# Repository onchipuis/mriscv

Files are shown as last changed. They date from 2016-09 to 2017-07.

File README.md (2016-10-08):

# mriscv

Building a pure RV32I Toolchain
-------------------------------

The default settings in the [riscv-tools](https://github.com/riscv/riscv-tools) build
scripts will build a compiler, assembler and linker that can target any RISC-V ISA,
but the libraries are built for RV32G and RV64G targets. Follow the instructions
below to build a complete toolchain (including libraries) that target a pure RV32I
CPU.

The following commands will build the RISC-V gnu toolchain and libraries for a
pure RV32I target, and install it in `/opt/riscv32i`:

    # Ubuntu packages needed:
    sudo apt-get install autoconf automake autotools-dev curl libmpc-dev libmpfr-dev \
            libgmp-dev gawk build-essential bison flex texinfo gperf libtool patchutils bc

    sudo mkdir /opt/riscv32i
    sudo chown $USER /opt/riscv32i

    git clone https://github.com/riscv/riscv-gnu-toolchain riscv-gnu-toolchain-rv32i
    cd riscv-gnu-toolchain-rv32i
    git checkout 7e48594
    git submodule update --init --recursive

    mkdir build; cd build
    ../configure --with-arch=RV32I --prefix=/opt/riscv32i
    make -j$(nproc)

The Microcontroller
-------------------

The microcontroller is composed by a 32b RISC-V core, a 4KB SRAM, a 10b ADC, a 12b DAC, 8 GPIO, and two SPI interfaces (master and slave). All the modules are conneted using two differente buses: AXI4 and APB.

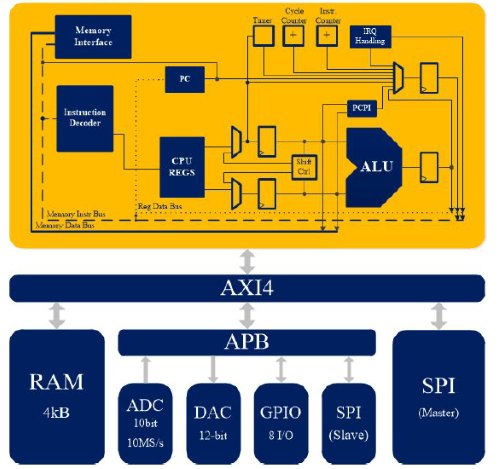
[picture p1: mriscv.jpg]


The directory tree is:

mriscv/mriscv_axi/ADC_interface_AXI     -----> ADC interface with the AXI4 bus

mriscv/mriscv_axi/AXI_SP32B1024         -----> SRAM memory interface

mriscv/mriscv_axi/DAC_interface_AXI     -----> DAC interface with the AXI4 bus

mriscv/mriscv_axi/axi4_interconnect     -----> the AXI4 bus

mriscv/mriscv_axi/impl_axi              -----> the microcontroller

mriscv/mriscv_axi/spi_axi_master        -----> master SPI used for programming

mriscv/mriscv_axi/spi_axi_slave         -----> slave SPI used for data adquisition

Development Board
-----------------

Also, there are a PCB design for the development board, including circuits for sensing analog signals and the capability to use  external clocks. The design is in mriscv/board

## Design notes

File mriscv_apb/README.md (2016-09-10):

mRISC-V code, APB version

NOTES:
Missing APB Peripherals (ADC, DAC, GPIO)
Minor differences only included (impl* and axi4_interconnect)
Same notes as AXI version.

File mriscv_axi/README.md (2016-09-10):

This is mRISC-V, AXI-version

NOTES:
Missing ADC, DAC and GPIO interfaces.
Cannot include the SP32B1024 (aka RAM) because disclaimer an alternate version using register will be included.
Generated versions of rc or encounter will not be included, just code.

TODO:
Create makefiles, because shell scripts are garbage.

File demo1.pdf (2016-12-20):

Demo 1 instructions.

1. Enter to the site: http://onchip.uis.edu.co
2. Put a name to the program, then login/SignIn using google clicking in the Google SignIn button.

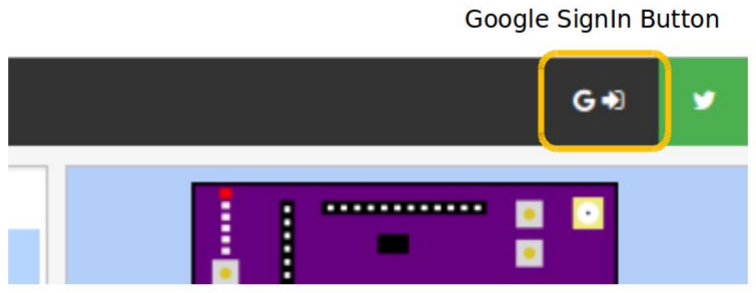
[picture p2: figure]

This is necessary in order to get access to the board. Otherwise login as guest to play with the interface, editor and RISC-V compiler.

3. Select the first button (board) on the right panel to work with the blinking demo.
4. You might choose the LED position that you want to blink as shown in fig. below.

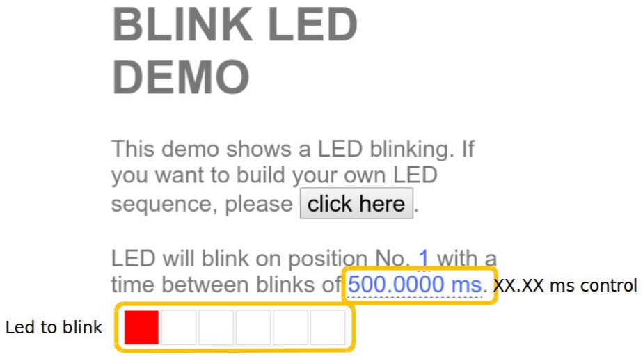
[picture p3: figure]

By dragging the clicked mouse over the time highlighted in blue, you would be able to change the blinking time. You also can drag the position to change the position of the blinking LED.

You will see the changes in the code as you change the highlighted variables.

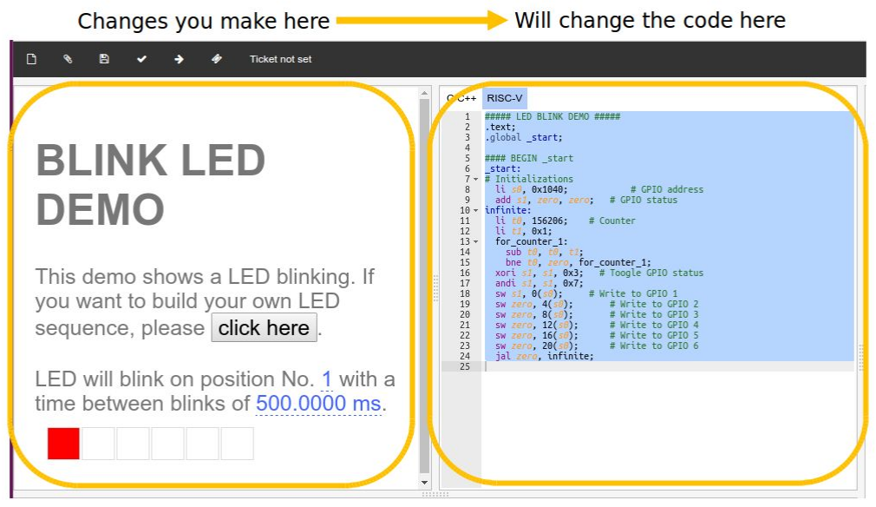
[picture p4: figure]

You would be able to change the code directly and re-write a different program as desired.

5. When your parameters are set, you’ll be able to compile & send the program to the open-v microcontroller in the dev. board. For compiling you need to click the “check” button.

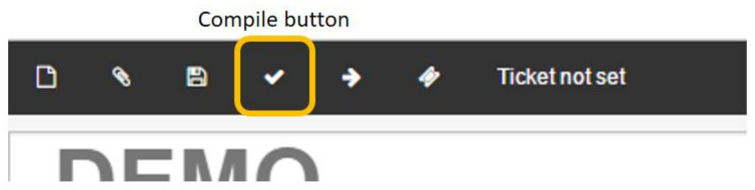
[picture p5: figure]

You can follow the compilation results on the console window.

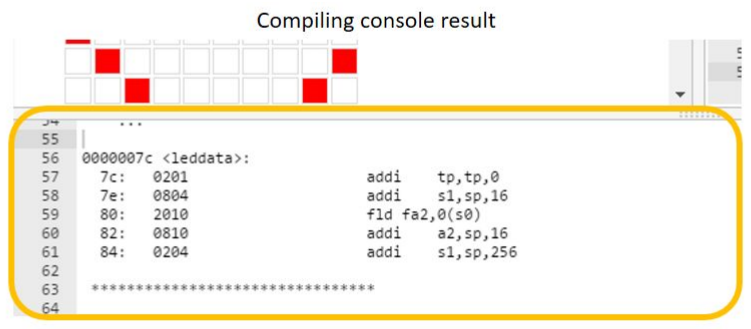
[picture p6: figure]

6. For sending the program to the dev. board, you need to request a ticket. You can request one to the server clicking the “ticket” button.

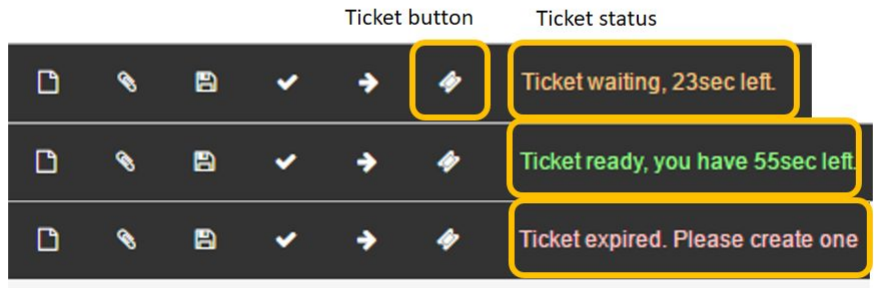
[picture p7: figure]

If your device time is net synced, you’ll see a second counter on the right of the button indicating how much time is left to program. If there are other pending tickets you need to wait.

The text will be colored Orange indicating how much time you need to wait to program. The text will be colored Green indicating you can program the board and how much time you have for this action.
The text will be colored Red indicating you need to request another ticket in order to program the device.
7. When you have permission to program using the ticket, click the “right arrow” button.

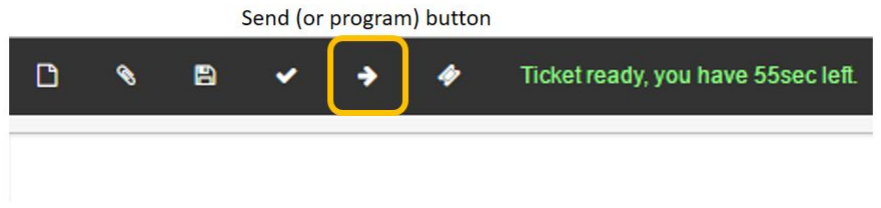
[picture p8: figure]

This process will take several seconds considering that the program is being send through a slow USB-to-SPI interface. When finished you will see the result in the console prompt and also on the board in the live video.

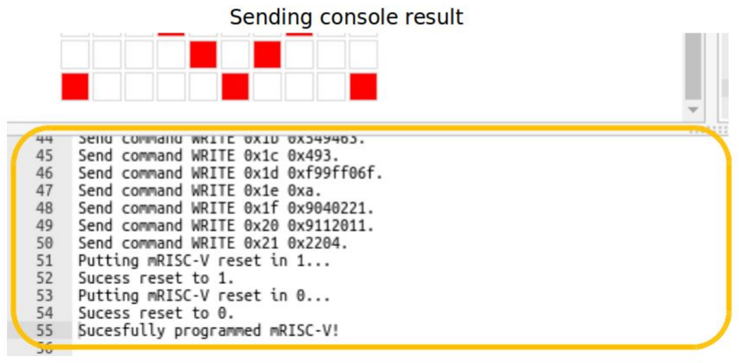
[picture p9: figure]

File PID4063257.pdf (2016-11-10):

# A 32-bit RISC-V AXI4-lite bus-based Microcontroller with 10-bit SAR ADC

Ckristian Duran, Luis Rueda D., Giovanny Castillo, Anderson Agudelo, Camilo Rojas, Luis Chaparro, Harry Hurtado, Juan Romero, Wilmer Ramirez, Hector Gomez, Javier Ardila, Luis Rueda, Hugo Hernandez, Jose Amaya and Elkim Roa Design Group of Integrated Systems CIDIC, Universidad Industrial de Santander, Bucaramanga, Colombia ckristian.duran@correo.uis.edu.co, efroa@uis.edu.co

Abstract—In this paper a complete implementation and design of a fully-synthesized 32-bit microcontroller in a 130nm CMOS technology is presented. This is the first microcontroller featuring the open source RISC-V instruction set all mounted through AXI4-Lite and APB buses for communication process. The microcontroller contains a 10-bit SAR ADC, a 12-bit DAC, an 8-bit GPIO module, a 4kB-RAM, an SPI AXI slave interface for output verification, and an SPI APB slave interface for checking the correct behavioral of the APB bridge. All peripherals are controlled by a RISC-V and an SPI AXI master interface that is used for programming the device and checking the data flowing through all the slaves. A total power density is reported as 167µW/MHz and the area for this RISC-V microcontroller has a reduced footprint of 798µm×484µm.
Keywords— RISC-V, AXI-4, APB, microcontroller, SAR ADC.
I. INTRODUCTION

Many commercial microcontrollers have been built to suit different requirements featuring many private-and-licensed instruction sets. Licensed instruction sets and microprocessor cores restrict the process of modifying the core for different purposes such as improving performance and adapting it to specific applications.
RISC-V is a new open ISA aimed to support architecture research and education [1]. It is fully available to the public and can replace ARM microprocessors because is comparable fast and has a small footprint size. RISC-V features an instruction set easy to migrate empowering a developer community to work on this new architecture. Recently, in [2] and [3] processors are reported capable of running linux using a RISC-V instruction set. However, up to date there has not been any reported work with of a small footprint RISC-V core for low-power microcontroller applications.
We are presenting the implementation of the first reported 32-bit RISC-V based microcontroller (mRISC-V). Our implementation and design is equivalent to commercial microcontrollers implemented with an ARM-M0 core. Features of this microcontroller are: AXI4-Lite and APB buses for interfacing communication between the core and all the peripherals attached to it, a 4kB-RAM, Serial Peripheral Interface (SPI) slaves for output, a GPIO module, a SAR Analog-to-Digital converter and a Digital-to-Analog converter. The circuit was designed using 130nm CMOS technology and tested using an efficient test algorithm in bus and using RISC-V tool-chain. In addition, a master SPI has been implemented in order to explore all the status of the peripherals while the microprocessor is still executing its program.

II. RISC-V

RISC-V is a new open instruction set architecture (ISA) designed by the Berkeley Architecture Group with the aim to support architecture research and education [1]. RISC-V is fully available to public and has advantages such as a smaller footprint size, support for highly-parallel multi-core or many-core implementations [2], variable-length instructions to support an optional dense instruction, and energy efficient. Moreover, RISC-V presents improvements in different characteristics over another open ISAs as shown the comparison in the Table I.

PARAMETER/ISA | SPARCV8 | OpenRISC | RISC-V
BASE+EXT | NO | NO | YES
Compact Code | NO | NO | YES
Quad FP | NO | NO | YES
32-bit | YES | YES | YES
64-bit | NO | YES | YES
128-bit | NO | NO | YES
GCC | YES | YES | YES
LLVM | YES | YES | YES
32-bit | YES | YES | YES

TABLE I: Comparison of the Open ISA

### R-type

### I-type

### S-type

### U-type

OPCODE

OPCODE

OPCODE

OPCODE

rd

rd

rd

imm[4:0]

funct3

funct3

funct3

imm[31:12]

rs1

rs1

rs1

rs2

imm[11:5] rs2

imm[11:0]

0 31 | 25 24 | 151920 | 111214 | 7 6 | bit
funct7

Fig. 1: RISC-V base instruction formats

The base ISA is clean and suitable for direct hardware implementation, the instructions of RISC-V are similar to

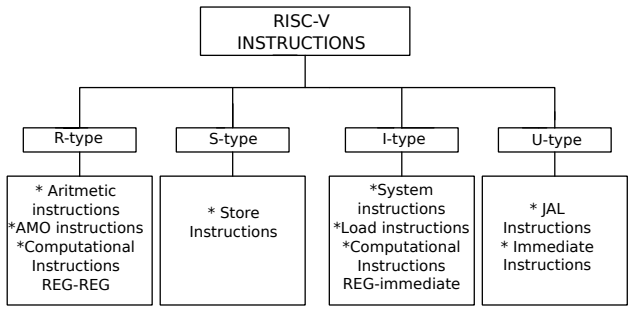
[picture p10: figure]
R-type; S-type; I-type; U-type; * Aritmetic instructions *AMO instructions *Computational Instructions REG-REG; * Store Instructions; *System instructions *Load instructions *Computational Instructions REG-immediate; * JAL Instructions * Immediate Instructions; RISC-V INSTRUCTIONS

Fig. 2: RISC-V Instructions

other RISC instructions set such as OpenRISC. The Fig. 1 shows the four core instruction formats (R,I,S,U). R-type format is used for several arithmetic instructions with one or two source operands and for the atomic memory operation (AMO) instructions that perform read-modify-write operations for multiprocessor synchronization. In addition, R-type is used for computational instruction register-register. I-type format is used for system instructions to access system functionality that might require privileged access and computational instructions register-immediate. Load and store instructions transfer a value between the registers and memory. Loads are encoded in the I-type format and stores are S-type. U-type format is used for JAL instructions or immediate instructions as LUI (load upper immediate) and AUIPC (add upper immediate to pc), see Fig.
2. All formats are fixed 32-bit in length, and keeps the source (rs1 and rs2) and destination (rd) registers at the same position to simply decoding, for all formats the bit 31 is the sign bit. RISC-V architecture contains an Arithmetic Logic Unit (ALU), registers, past memory and future memory, an interrupt system, an instruction decoder and a Pico co-processor interface (PCPI) which is connected to a co-processor to do multiplications. We have implemented a reduced instruction set microcontroller mRISC-V, described in verilog, using a smaller core to promote research and development of the internet of things. According to [1], the implemented sub-set of instructions are RV32I Base Integer Instruction Set (all) and ”M” Standard Extension for Integer Multiplication and Division (only MUL[H[SU—U]]).

III. MRISC-V ARCHITECTURE
Implementation of an efficient microcontroller requires a reliable and fast communication between masters and slaves blocks in the microcontroller. Nowadays, many bus-based communication architecture standards are found. In this work we are using the AMBA and APB protocols such that we can compare with microcontrollers based on ARM-M0 cores. The architecture of the mRISC-V is shown in Fig. 3.
Slave interfaces are interconnected to the AXI4-Lite or to the APB Bridge. Each interface is different but with several similarities for each protocol. Buses are composed of state machines, registers, multiplexers and Hi-Z buffers. Moreover, the master interface is implemented with a Serial Peripheral Interface (SPI). Following sections describe all these interfaces.

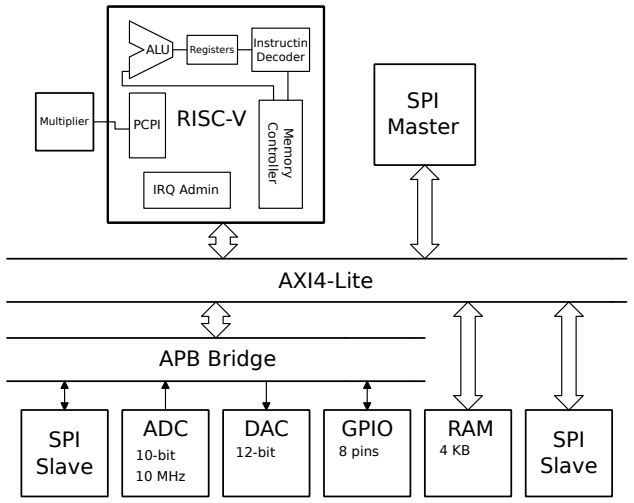
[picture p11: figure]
Multiplier; ALU; Registers; Instructin; Decoder; PCPI RISC-V; IRQ Admin; Memory; Controller; SPI Master; AXI4-Lite; APB Bridge; ADC; 10-bit 10 MHz; SPI Slave; RAM; GPIO; 8 pins; DAC; 12-bit

Fig. 3: mRISC-V block diagram.

A. AXI4-Lite

The AMBA AXI4 is an ultra-high performance protocol bus standard [4] developed by ARM for easy application in small scale SoCs. AXI4 has different forms to be implemented and this work uses the AXI4-Lite protocol, which has two data channels of 32-bit and other necessary control signals for communication between Masters (SPI M, RISC-V) and slaves (RAM, SPI S, APB) [5].
According to the AXI4 specification, communication between the masters and the slaves must be done through an Interconnect module. For this application the AXI4-Lite interconnect has been implemented following specification.
B. SPI Master

SPI is used as a master AXI4-Lite interface for controlling all slaves attached to the core. This interface has a 66-bit data instruction: 32-bit for data, 32-bit for address and 2-bit to define an action like write, read; to put the core reset; and check the last request. This is a fully custom design for debugging and programming purposes.

C. APB

Several types of protocols are available in SoC, which require a bridge to safely pass the information from one type of protocol to another without data loss. The Advance Peripheral Bus (APB) is part of the Advaced Microcontroller Bus Architecture (AMBA) protocol family. This protocol determines a low-cost interface that is optimized for minimal power expending and decreased interface complexity used to connect to low-bandwidth peripherals that do not demand the high performance of the AXI protocol.
The signal transaction between AXI master and APB slave are described by:
- AMBA AXI-Lite signals as described in the AMBA AXI-Lite 4.0 protocol specification. [5]

- AMBA APB signals as described in the AMBA APB 4.0 protocol specification. [6]
The APB bridge provides an interface between the highspeed AXI domain and the low-power APB domain. It’s seen as slave on AXI but as a master on APB. To run a process of writing or reading transfers on the AXI bus are converted into corresponding transfers on the APB. This conversion is described in verilog applying the respective protocol specifications. Since its execution is not pipelined, wait states and response signals of protocol are added during transfers to and from the APB when the AXI must wait for the APB protocol.
The APB bridge is responsible for converting the APB signals corresponding AXI signals. The APB bridge acts as master in APB module and all transactions initiated by the AXI masters. Whenever AXI master tries to access a slave, it requires completing the handshaking process with the corresponding slave. When the AXI master wants to start a process of writing and reading simultaneously in any of the peripherals, reading takes priority and the writing process can take place after completion of the read transaction.

IV. PERIPHERALS

A. GPIO
General-purpose input/output (GPIO) are crucial for a variety of microcontroller applications and these pins are used as digital inputs or outputs. Figure 4 shows the block diagram of communication between the core and the pad, which perform the connection of the GPIO with the APB bridge protocol. This block is controlled by a digital control system designed for speed and low power consumption according to the APB Bridge protocol. The implemented GPIO have slewrate control capability for output and Schmit-Trigger windows for input. The 8-port GPIO is able to drive up to 25mA per

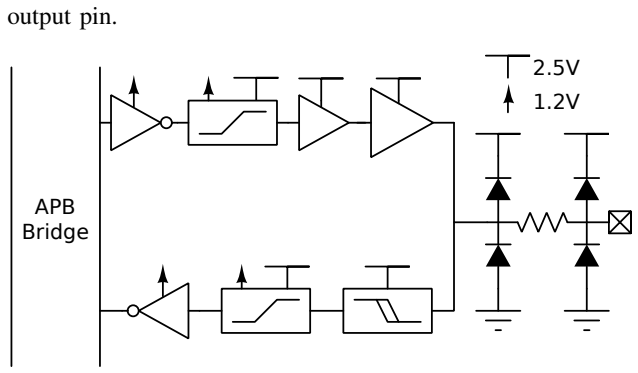
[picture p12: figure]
output pin.; APB Bridge

Fig. 4: GPIO block diagram.

B. ANALOG AND DIGITAL CONVERTERS
In order to perform analog and digital conversions, mRISC-V incorporates an analog-to-digital converter (ADC) and a digital-to-analog converter (DAC) which communicate with APB Bridge through the interface shown in Fig. 3. The ADC type that is implemented is a successive approximation register (SAR) and its structure is shown in Fig. 5. The SAR ADC implemented operates at a maximum sampling frequency of 10MHz and a resolution of 10-bit for a differential input.

BOOSTTRAPED

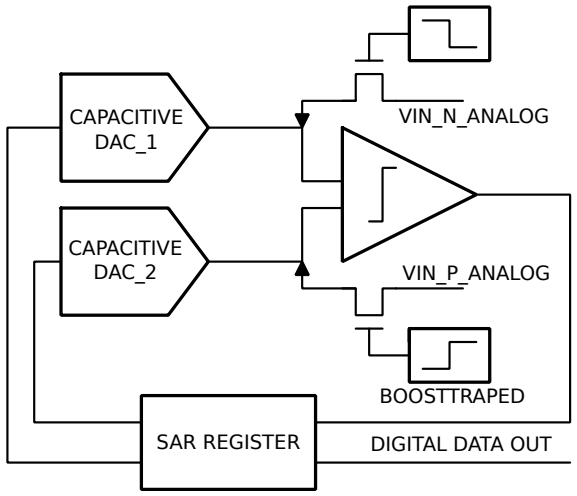
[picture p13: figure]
CAPACITIVE DAC_1; SAR REGISTER; VIN_N_ANALOG; VIN_P_ANALOG; BOOSTTRAPED; DIGITAL DATA OUT; CAPACITIVE DAC_2

Fig. 5: SAR ADC block diagram.

On the other hand, the DAC implemented is based in a R2R structure with 12-bit resolution, rail to rail output voltage and a typical settling time of 100ns.

V. RESULTS

Verification of peripherals has been performed from the perspective of the RISC-V core and the SPI master. The SPI master is used to program the memory and also can read or write on any peripheral attached to the AXI-4 bus and the APB bridge. Fig. 6 shows the used initialization and verification tasks where signal generation and communications transactions are shown in Fig. 7.
A methodology is described in verilog which perfom an automatic verification of random handshake generation in the AXI master 1 and AXI master 2. As the first step, the AXI master choose a slave, then the transaction type is selected (read or write) depending of type transaction that can support the slave. The data is sent to the bus and the AXI scoreboard registers of the data flow between the master and the slave. The data is kept and compared to verify that the transaction is correct. In case of a violation in the protocol, the verification process is paused and the error is reported to the prompt. Microcontroller is fully synthesized in 130nm CMOS technology. Synthesis results are shown in the Table II for each peripherals and for whole system with the AXI-APB implementation. The 4kB RAM module occupies almost the same area of the sum of the core and peripherals. The highest power consumption density comes from the RISV-V processor. Maximum operation frequency is determined by the RAM which operates at 100MHz despite the core been able to

### Programming mRISC-V through SPI

### Execute mRISC-V and wait "OK"

### Test DAC from SPI

### Test ADC from SPI

### Test GPIO from SPI

### mRISC-V async execution

Fig. 6: Initialization and testing setup for mRISC-V.

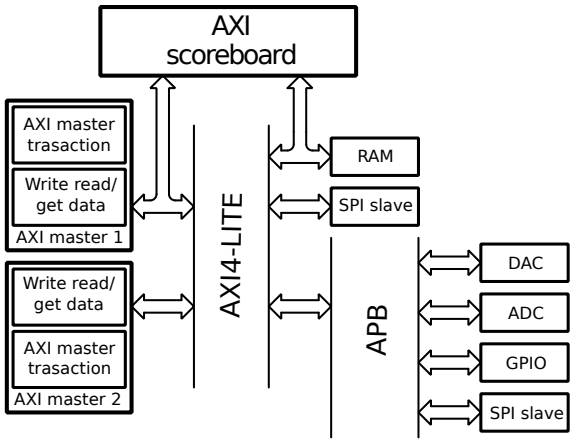
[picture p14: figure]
AXI scoreboard; AXI master 2; AXI master 1; AXI master trasaction; Write read/ get data; RAM; SPI slave; APB; AXI4-LITE; GPIO; ADC; DAC

Fig. 7: Testbench architecture.

operate at higher frequency. Some cores, especially the AXI-4 interconnect, uses Hi-Z addressing instead of multiplexer to optimize area. The sum of the peripherals implemented on APB (ADC, DAC and GPIO) are on the APB TOP implementation.
The final layout is exposed in the Fig. 8. Each instance is highlighted to expose the area breakout. As expected, the RAM block occupies a significant area with a footprint close to 50% of the whole chip. A final area of 798µm×484µm and an energy consumption of about 167µW/Hz shows the feasibility of using the proposed mRISC-V -with additional sensor circuitry- in and low-cost and low-power applications.

VI. SUMMARY

A fully-synthesized microncontroller based on RISC-V architecture on 130nm CMOS technology has been presented. Many peripherals are included using a proposed methodology to verify the correct operation. The proposed architecture shows the interconnection between the RISC-V, the SPI AXI master, and all the peripherals attached to the AXI4-Lite and APB buses, explaining details of the implementation.
The proposed mRISC-V is the first designed RISC-V microcontroller with enough peripheral to perform common microcontroller tasks. Power and area results show that a reduced RISC-V architecture can be used to replace ARM-MO based microcontrollers with similar peformance. Considering the advantage of the growing RISC-V community and the
Core | Power | Time Slack | Area
| [nW/MHz] | [ps@100MHz] | [µm² ]
AXI-4 bus | 5284.66 | 6093 | 11830
mRISC-V | 96952.67 | 2143 | 120776
SPI AXI master | 13532.69 | 3998 | 19627
AXI-RAM | 2617.00 | 3602 | 2580
RAM | 18997.73 | N/A | 168708
APB TOP | 11703.14 | 3664 | 23794
SPI AXI slave | 2176.93 | 8085 | 1899
All | 166841.47 | 1185 | 349233

TABLE II: Power, timing and area breakout of the mRISC-V.

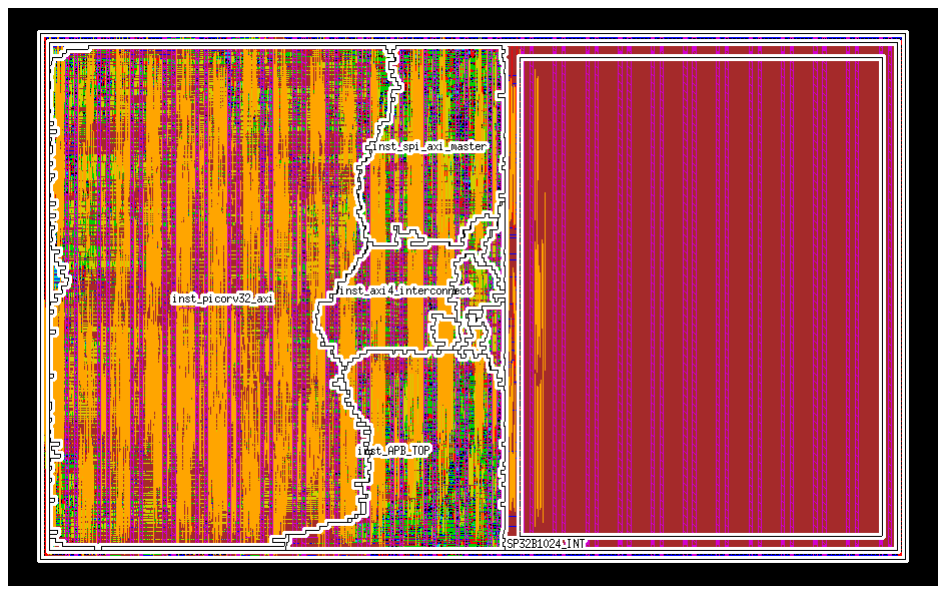
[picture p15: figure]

Fig. | 8: | Final | layout | for | AXI-APB | implementation.
Area:798µm×484µm

existing tool-chain and software around this new instruction set, the mRISC-V paves the way of future implementations for specific and general applications in the world of IoT with open source devices.

REFERENCES

[1] A. Waterman, Y. Lee, D. A. Patterson, and K. Asanovi, “The RISC-V instruction set manual, volume i: User-level ISA, version 2.0,” EECS Department, University of California, Berkeley, Tech. Rep. UCB/EECS-2014-54, May 2014.
[2] Y. Lee, A. Waterman, R. Avizienis, H. Cook, C. Sun, V. Stojanovic, and
K. Asanovic, “A 45nm 1.3GHz 16.7 double-precision GFLOPS/W RISC-V processor with vector accelerators,” in European Solid State Circuits Conference (ESSCIRC), ESSCIRC 2014 - 40th, Sept 2014, pp. 199–202.
[3] B. Zimmer et al., “A RISC-V vector processor with tightly-integrated switched-capacitor DC-DC converters in 28nm FDSOI,” in 2015 Symposium on VLSI Circuits, pp. C316–C317, June 2015.
[4] S. Pradeep and C. Laxmi, “Design and verification environment for AMBA AXI protocol for SOC integration,” NCRIET-2014, vol. 3, no. 3, pp. 338–343, may 2014.
[5] ARM, “AMBA AXI and ACE protocol specification,” 2011, pp. 1–121.
[6] C. Ma, Z. Liu, and X. Ma, “Design and implementation of apb bridge based on amba 4.0,” in International Conference on Consumer Electronics, Communications and Networks (CECNet), pp. 193–196, April 2011.

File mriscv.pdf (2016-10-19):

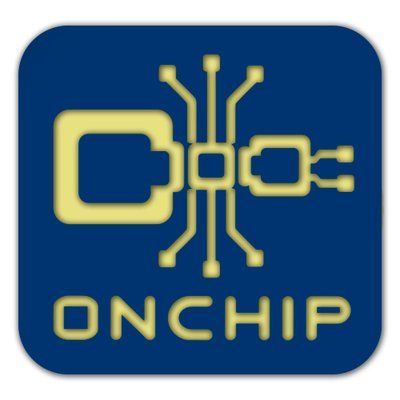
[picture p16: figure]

## @onchipUIS

### A 130nm 32-bit RISC-V microcontroller

### Who we are

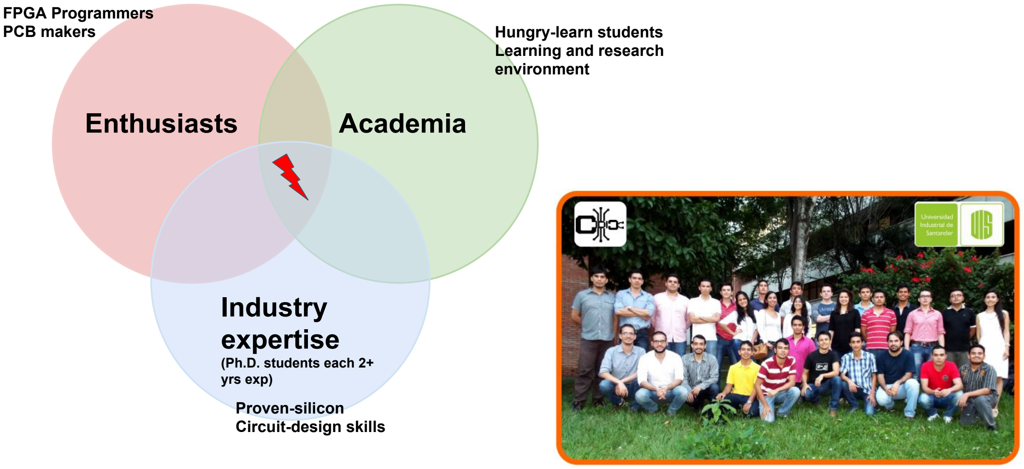
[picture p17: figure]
Enthusiasts; Academia; Industry expertise; (Ph.D. students each 2+ yrs exp); FPGA Programmers; PCB makers; Hungry-learn students; Learning and research environment; Proven-silicon Circuit-design skills
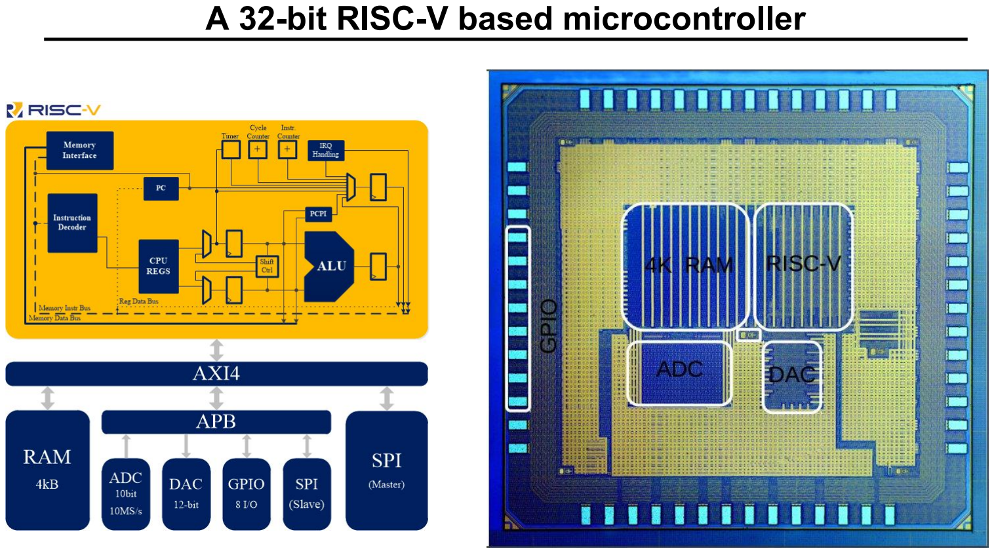
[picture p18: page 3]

### A 32-bit RISC-V based microcontroller

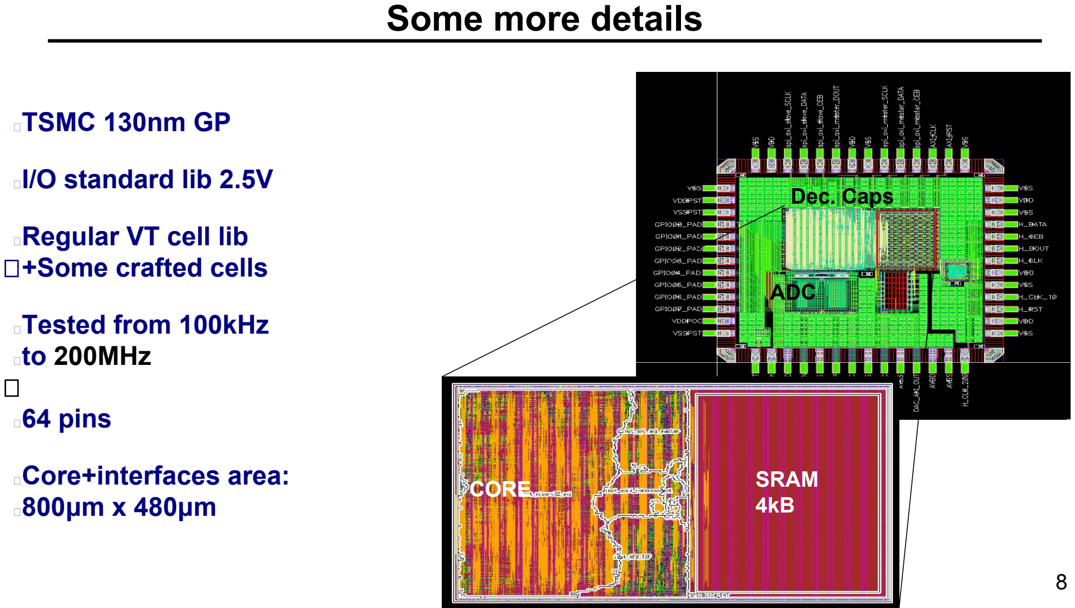
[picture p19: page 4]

### Some more details

TSMC 130nm GP

I/O standard lib 2.5V

Regular VT cell lib
+Some crafted cells

Tested from 100kHz
to 200MHz
64 pins

Core+interfaces area:
800μm x 480μm | CORE | SRAM
| | 4kB

ADC

Dec. Caps

8

Performance

μRISC-V

ISA | RV32IM
Architecture | Single-Issue In-Order 3-stage
Process Die Area | TSMC 130nm GP
| 2.1mm x 2.1mm
uP core area | 0.12 mm² !
Max. Frequency | 100MHz
Core Voltage I/O Voltage | 1.2 V 2.5V
Core Dynamic Power 1.2V Current @2.5MHz | 132 μW/MHz *
| 1.8mA

! Fully constrained clock and loads for SSLHH corner. Zero skew CTS.
* Measured at 100MHz running three while loops.
Clock Frequency [MHz]` | Total Current (1.2V and 2.5V supplies ) [mA]

2.5 2.5

5 4.62

8.8 5.01

10 5.12

20 6.13

40 8.10

60 10.20

80 12.18

100 14.13

120 16.14

140 18.09

160 20.06

180 21.89

200 23.76

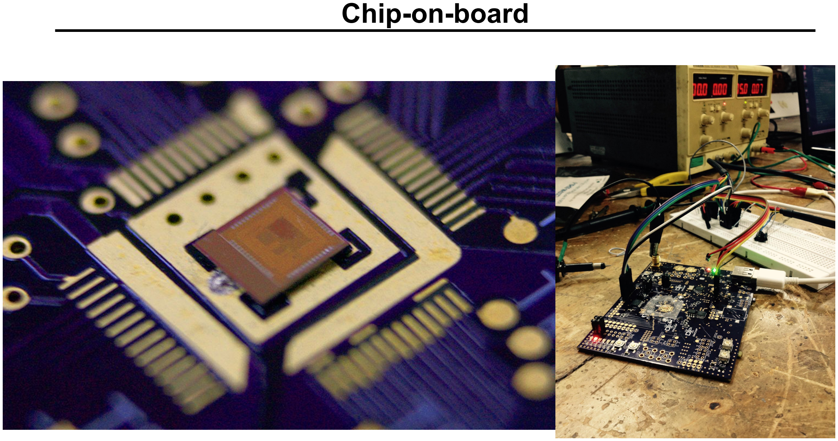
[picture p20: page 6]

### Chip-on-board

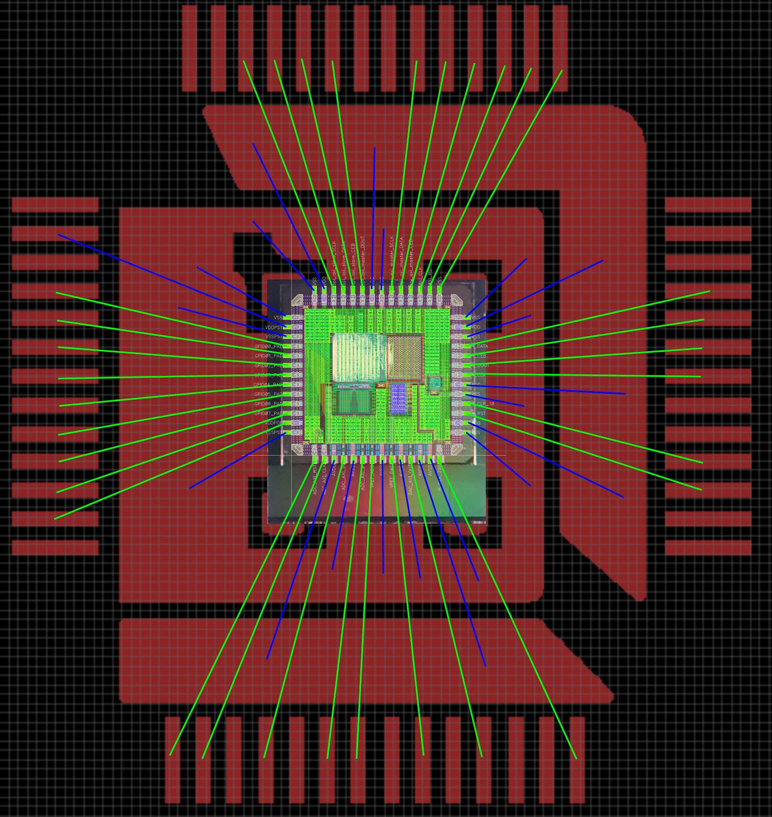
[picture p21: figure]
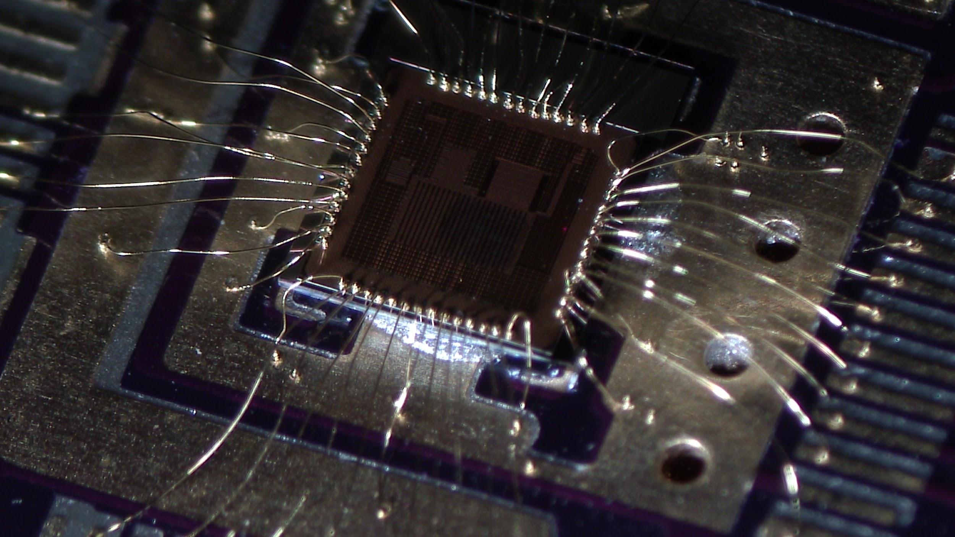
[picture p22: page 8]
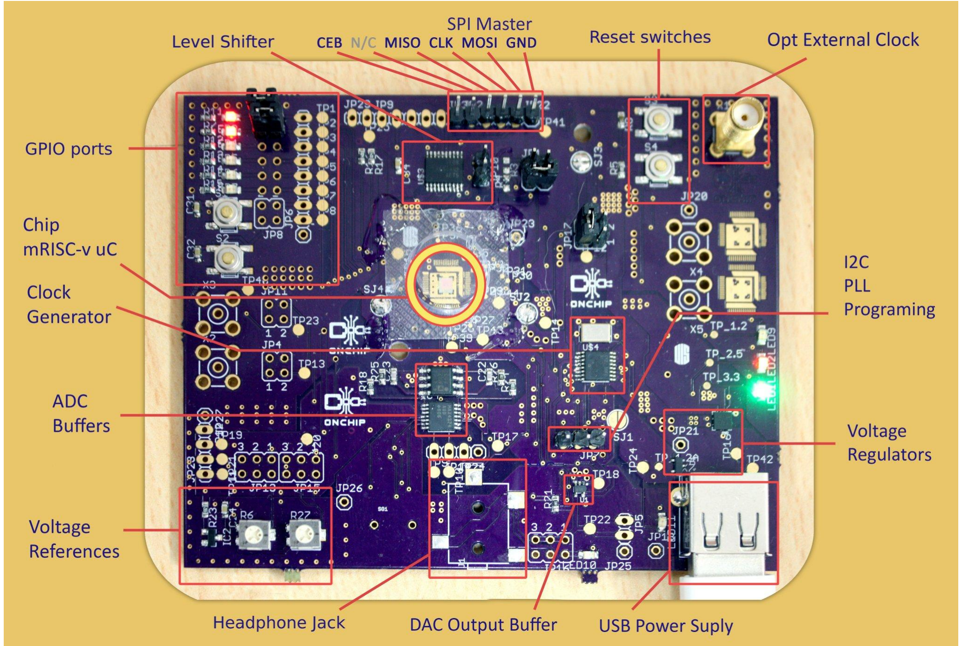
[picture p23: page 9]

### Give sth that has no bugs

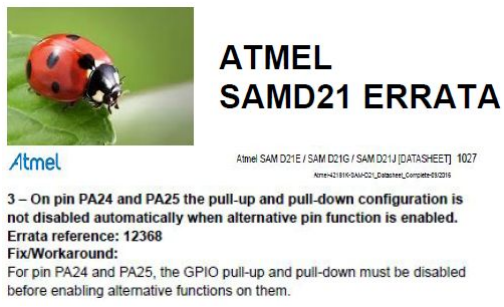
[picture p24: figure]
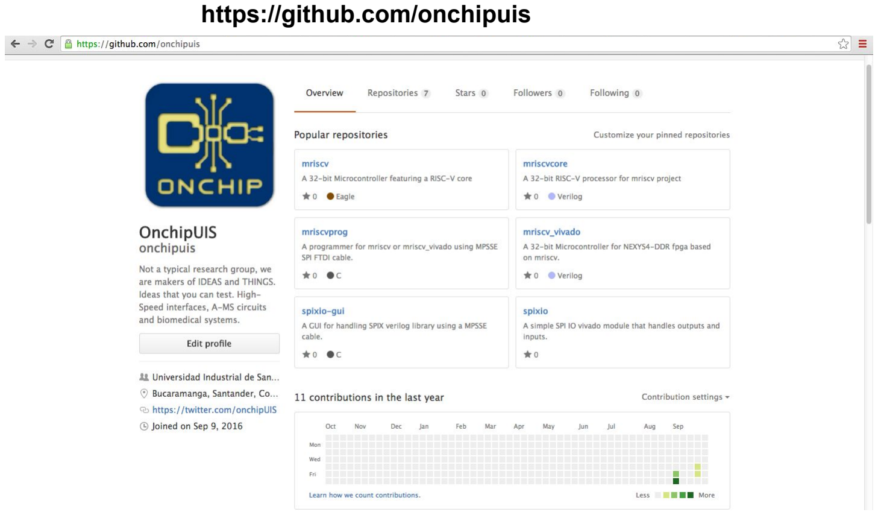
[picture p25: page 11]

https://github.com/onchipuis


### Tools for VLSI grad students

RTL Code; ESD; Biasing; Data converters; Power; Integrity; Layout; PLL; Clock distribution; Sign-off; Signal Integrity; Verification

Lot of circuits, lot of skills

Diving into...

Q3-Q4 2015 RTL + Analog Design; Q1 2017 Tape Out V.2 +CNN +NVRAM; Q2 2015 Microcontroller Specs; Q4 2015 Tape Out; Q3 2016 Testing; Q2 2018 Puzzle Boards

Some more details

Chip is back


Logo programming →
New programming model

### A New Kind of Market

### Thanks to:

### - SAMPA Project - ALICE-CERN - Clifford Wolf - RISC-V foundation - Oshpark - TPT


- LPDDR3/LPDDR4 PCS + PMA
- USB 3.1 PCS + PMA (10Gb/s)
- LPDDR3/4 UVM VIP
- Circuits for Security: Lite key exchanging, TRNGs
- Research on CDR architectures
- Research on lite CNN
- Research on DFE + on-fly offset correction

### What else we are doing:

New chip has just arrived!

- Kickstarter microcontroller for a try to replace Atmel SAMD21? → $350k for 70k packaged and tested chips, 2 revisions!
- Share MPW costs with more teams. Any school or private group want to team up?
- Foundries should start looking at these initiatives and fund “free” prototype silicon. High-level contacts are welcome.
- USB 2.0/3.1 PHY effort on indiegogo?
- Maybe RasberryPi or Arduino guys are willing to get some really open silicon?
IDEAS ARE WELCOME

### Funding is welcome

### Demo before dinner, tonight!

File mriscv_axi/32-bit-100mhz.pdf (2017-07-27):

# A 32-bit 100MHz RISC-V Microcontroller with 10-bit SAR ADC in 130nm CMOS

Ckristian Duran, Luis Rueda D., Giovanny Castillo, Anderson Agudelo,

### Camilo Rojas, Luis Chaparro, Harry Hurtado, Juan Romero, Wilmer

Ramirez, Hector Gomez, Javier Ardila, Luis Rueda, Rolando Torres,

### Hugo Hernandez, Jose Amaya and Elkim Roa

### Design Group of Integrated Systems CIDIC, Universidad Industrial de Santander, Bucaramanga, Colombia ckristian.duran@correo.uis.edu.co, efroa@uis.edu.co

Abstract

In this paper a complete implementation and design of a fully-synthesized 32-bit microcontroller in a 130nm CMOS technology is presented. This is the first microcontroller featuring the open source RISC-V instruction set all mounted through AXI4-Lite and APB buses for communication process. The microcontroller contains a 4kB-RAM, an SPI AXI slave interface for output verification, and an SPI APB slave interface for checking the correct behavioral of the APB bridge. All peripherals are controlled by a RISC-V and an SPI AXI master interface that is used for programming the device and checking the data flowing through all the slaves. A total power density is reported as 167µW/MHz and the area for this RISC-V microcontroller has a reduced footprint of 798µm×484µm.

## 1 Introduction

Many commercial microcontrollers have been built to suit different requirements featuring many private-and-licensed instruction sets. Licensed instruction sets and microprocessor cores restrict the process of modifying the core for different purposes such as improving performance and adapting it to specific applications.
RISC-V is a new open ISA aimed to support architecture research and education [1]. It is fully available to the public and can replace ARM microprocessors because is comparable fast and has a small footprint size. RISC-V features an instruction set easy to migrate empowering a developer community to work on this new architecture. Recently, in [2] and [3] processors are reported capable of running linux using a RISC-V instruction set. However, up to date there has not been any reported work with of a small footprint RISC-V core for low-power microcontroller applications.
We are presenting the implementation of the first reported 32-bit RISC-V based microcontroller (mRISC-V). Our implementation and design is equivalent to commercial microcontrollers implemented with an ARM-M0 core. Features of this microcontroller are: AXI4-Lite and APB buses for interfacing communication between the core and all the peripherals attached to it, a 4kB-RAM, Serial Peripheral Interface (SPI) slaves for output, a GPIO module, a SAR Analog-to-Digital converter and a Digital-to-Analog converter. The circuit was designed using 130nm CMOS technology and tested using an efficient test algorithm in bus and using RISC-V tool-chain. In addition, a master SPI has been implemented in order to explore all the status of the peripherals while the microprocessor is still executing its program.

## 2 RISC-V

RISC-V is a new open instruction set architecture (ISA) designed by the Berkeley Architecture Group with the aim to support architecture research and education [1]. RISC-V is fully available to public and has advantages such as a smaller footprint size, support for highly-parallel multi-core or many-core implementations [2], variable-length instructions to support an optional dense instruction, and energy efficient. Moreover, RISC-V presents improvements in different characteristics over another open ISAs as shown the comparison in the Table 1.

Table 1: Comparison of the Open ISA
PARAMETER/ISA | SPARCV8 | OpenRISC | RISC-V
BASE+EXT | NO | NO | YES
Compact Code | NO | NO | YES
Quad FP | NO | NO | YES
32-bit | YES | YES | YES
64-bit | NO | YES | YES
128-bit | NO | NO | YES
GCC | YES | YES | YES
LLVM | YES | YES | YES
32-bit | YES | YES | YES

# R-type

# I-type

# S-type

# U-type

OPCODE

OPCODE

OPCODE

OPCODE

rd

rd

rd

## imm[4:0]

## funct3

## funct3

## funct3

## imm[31:12]

rs1

rs1

rs1

rs2

## imm[11:5] rs2

## imm[11:0]

0 31 | 25 24 | 151920 | 111214 | 7 6 | bit

## funct7

Figure 1: RISC-V base instruction formats

The base ISA is clean and suitable for direct hardware implementation, the instructions of RISC-V are similar to other RISC instructions set such as OpenRISC. The Fig. 1

R-type; S-type; I-type; U-type; * Aritmetic instructions *AMO instructions *Computational Instructions REG-REG; * Store Instructions; *System instructions *Load instructions *Computational Instructions REG-immediate; * JAL Instructions * Immediate Instructions; RISC-V INSTRUCTIONS

Figure 2: RISC-V Instructions

shows the four core instruction formats (R,I,S,U). R-type format is used for several arithmetic instructions with one or two source operands and for the atomic memory operation (AMO) instructions that perform read-modify-write operations for multiprocessor synchronization. In addition, R-type is used for computational instruction register-register. I-type format is used for system instructions to access system functionality that might require privileged access and computational instructions register-immediate. Load and store instructions transfer a value between the registers and memory. Loads are encoded in the I-type format and stores are S-type. U-type format is used for JAL instructions or immediate instructions as LUI (load upper immediate) and AUIPC (add upper immediate to pc), see Fig. 2. All formats are fixed 32-bit in length, and keeps the source (rs1 and rs2) and destination (rd) registers at the same position to simply decoding, for all formats the bit 31 is the sign bit.
RISC-V architecture contains an Arithmetic Logic Unit (ALU), registers, past memory and future memory, an interrupt system, an instruction decoder and a Pico co-processor interface (PCPI) which is connected to a co-processor to do multiplications. We have implemented a reduced instruction set microcontroller mRISC-V using a smaller core to promote research and development of the Internet of things.

## 3 mRISC-V ARCHITECTURE

Implementation of an efficient microcontroller requires a reliable and fast communication between masters and slaves blocks in the microcontroller. Nowadays, many bus-based communication architecture standards are found. In this work we are using the AMBA and APB protocols such that we can compare with microcontrollers based on ARM-M0 cores. The architecture of the mRISC-V is shown in Fig. 3.
Slave interfaces are interconnected to the AXI4-Lite or to the APB Bridge. Each interface is different but with several similarities for each protocol. Buses are composed of state machines, registers, multiplexers and Hi-Z buffers. Moreover, the master interface

Multiplier

ALU | Registers | Instructin Decoder

## PCPI RISC-V

IRQ Admin

Memory

Controller

## SPI Master

## AXI4-Lite

APB Bridge; ADC; 10-bit 10 MHz; SPI Slave; RAM; GPIO; 8 pins; DAC; 12-bit

Figure 3: mRISC-V block diagram.

is implemented with a Serial Peripheral Interface (SPI). Following sections describe all these interfaces.

### 3.1 AXI4-Lite

The AMBA AXI4 is an ultra-high performance protocol bus standard [4] developed by ARM for easy application in small scale SoCs. AXI4 has different forms to be implemented and this work uses the AXI4-Lite protocol, which has two data channels of 32-bit and other necessary control signals for communication between Masters (SPI M, RISC-
V) and slaves (RAM, SPI S, APB) [5].

### 3.2 SPI Master

SPI is used as a master AXI4-Lite interface for controlling all slaves attached to the core. This interface has a 66-bit data instruction: 32-bit for data, 32-bit for address and 2-bit to define an action like write, read; to put the core reset; and check the last request.

### 3.3 APB

Several types of protocols are available in SoC, which require a bridge to safely pass the information from one type of protocol to another without data loss. The Advance Peripheral Bus (APB) is part of the Advaced Microcontroller Bus Architecture (AMBA) protocol family. This protocol determines a low-cost interface that is optimized for minimal power expending and decreased interface complexity used to connect to low-bandwidth peripherals that do not demand the high performance of the AXI protocol.
The signal transaction between AXI master and APB slave are described by:
- AMBA AXI-Lite signals as described in the AMBA AXI-Lite 4.0 protocol specification. [5]
- AMBA APB signals as described in the AMBA APB 4.0 protocol specification. [6]

The APB bridge provides an interface between the high-speed AXI domain and the low-power APB domain. It’s seen as slave on AXI but as a master on APB. To run a process of writing or reading transfers on the AXI bus are converted into corresponding transfers on the APB. Since its execution is not pipelined, wait states and response signals of protocol are added during transfers to and from the APB when the AXI must wait for the APB protocol.
The APB bridge is responsible for converting the APB signals corresponding AXI signals. The APB bridge acts as master in APB module and all transactions initiated by the AXI masters. Whenever AXI master tries to access a slave, it requires completing the handshaking process with the corresponding slave. When the AXI master wants to start a process of writing and reading simultaneously in any of the peripherals, reading takes priority and the writing process can take place after completion of the read transaction.

## 4 PERIPHERALS

### 4.1 GPIO

General-purpose input/output (GPIO) are crucial for a variety of microcontroller applications and these pins are used as digital inputs or outputs. Figure 4 shows the block diagram of communication between the core and the pad, which perform the connection of the GPIO with the APB bridge protocol. This block is controlled by a digital control system designed for speed and low power consumption according to the APB Bridge protocol. The implemented GPIO have slew-rate control capability for output and Schmit-Trigger windows for input. The 8-port GPIO is able to drive up to 25mA per output pin.

### 4.2 ANALOG AND DIGITAL CONVERTERS

In order to perform analog and digital conversions, mRISC-V incorporates an analogto-digital converter (ADC) and a digital-to-analog converter (DAC) which communicate with APB Bridge through the interface shown in Fig. 3. The ADC type that is implemented is a successive approximation register (SAR) and its structure is shown in Fig. 5. The SAR ADC implemented operates at a maximum sampling frequency of 10MHz and

APB Bridge

Figure 4: GPIO block diagram.

a resolution of 10-bit for a differential input.

BOOSTTRAPED

CAPACITIVE DAC_1; SAR REGISTER; VIN_N_ANALOG; VIN_P_ANALOG; BOOSTTRAPED; DIGITAL DATA OUT; CAPACITIVE DAC_2

Figure 5: SAR ADC block diagram.

On the other hand, the DAC implemented is based in a R2R structure with 12-bit resolution, rail to rail output voltage and a typical settling time of 100ns.

## 5 RESULTS

Verification of peripherals has been performed from the perspective of the RISC-V core and the SPI master. The SPI master is used to program the memory and also can read or write on any peripheral attached to the AXI-4 bus and the APB bridge. Fig. 6 shows the used initialization and verification tasks where signal generation and communications transactions are shown in Fig. 7.

A methodology is described in verilog which perfom an automatic verification of random handshake generation in the AXI master 1 and AXI master 2. As the first step, the AXI master choose a slave, then the transaction type is selected (read or write) depending of type transaction that can support the slave. The data is sent to the bus and the AXI scoreboard registers of the data flow between the master and the slave. The data is kept and compared to verify that the transaction is correct. In case of a violation in the protocol, the verification process is paused and the error is reported to the prompt.

## Programming mRISC-V through SPI

## Execute mRISC-V and wait "OK"

## Test DAC from SPI

## Test ADC from SPI

## Test GPIO from SPI

## mRISC-V async execution

Figure 6: Initialization and testing setup for mRISC-V.

AXI scoreboard; AXI master 2; AXI master 1; AXI master trasaction; Write read/ get data; RAM; SPI slave; APB; AXI4-LITE; GPIO; ADC; DAC

Figure 7: Testbench architecture.

Microcontroller is fully synthesized in 130nm CMOS technology. Synthesis results are shown in the Table 2 for each peripherals and for whole system with the AXI-APB implementation. The 4kB RAM module occupies almost the same area of the sum of the core and peripherals. The highest power consumption density comes from the RISV-V processor. Maximum operation frequency is determined by the RAM which operates at 100MHz despite the core been able to operate at higher frequency. Some cores, especially the AXI-4 interconnect, uses Hi-Z addressing instead of multiplexer to optimize area. The sum of the peripherals implemented on APB (ADC, DAC and GPIO) are on the APB TOP implementation.

Table 2: Power, timing and area breakout of the mRISC-V.
Core | Power [nW/MHz] | Time Slack [ps @ 100MHz] | Area [µm² ]
AXI-4 interconnect | 5284.66 | 6093 | 11830
mRISC-V | 96952.67 | 2143 | 120776
SPI AXI master | 13532.69 | 3998 | 19627
AXI-RAM | 2617.00 | 3602 | 2580
RAM | 18997.73 | N/A | 168708
APB TOP | 11703.14 | 3664 | 23794
SPI AXI slave | 2176.93 | 8085 | 1899
All | 166841.47 | 1185 | 349233

The final layout is exposed in the Fig. 8. Each instance is highlighted to expose the area breakout. As expected, the RAM block occupies a significant area with a footprint close to 50% of the whole chip. A final area of 798µm×484µm and an energy consumption of about 167µW/Hz shows the feasibility of using the proposed mRISC-V -with additional sensor circuitry- in and low-cost and low-power applications.


Figure 8: Final layout for AXI-APB implementation. Area:798µm×484µm

## 6 SUMMARY

A fully-synthesized microncontroller based on RISC-V architecture on 130nm CMOS technology has been presented. Many peripherals are included using a proposed methodology to verify the correct operation. The proposed architecture shows the interconnection between the RISC-V, the SPI AXI master, and all the peripherals attached to the AXI4-Lite and APB buses, explaining details of the implementation.
The proposed mRISC-V is the first designed RISC-V microcontroller with enough peripheral to perform common microcontroller tasks. Power and area results show that a reduced RISC-V architecture can be used to replace ARM-MO based microcontrollers with similar peformance. Considering the advantage of the growing RISC-V community and the existing tool-chain and software around this new instruction set, the mRISC-V paves the way of future implementations for specific and general applications in the world of IoT with open source devices.

## References

[1] A. Waterman, Y. Lee, D. A. Patterson, and K. Asanovic, “The RISC-V instruction ´ set manual, volume i: User-level ISA, version 2.0,” EECS Department, University of California, Berkeley, Tech. Rep. UCB/EECS-2014-54, May 2014.
[2] Y. Lee, A. Waterman, R. Avizienis, H. Cook, C. Sun, V. Stojanovic, and K. Asanovic, “A 45nm 1.3GHz 16.7 double-precision GFLOPS/W RISC-V processor with vector accelerators,” in European Solid State Circuits Conference (ESSCIRC), ESSCIRC 2014 - 40th, Sept 2014, pp. 199–202.
[3] B. Zimmer, Y. Lee, A. Puggelli, J. Kwak, R. Jevtic, B. Keller, S. Bailey, M. Blagojevic, P.-F. Chiu, H.-P. Le, P.-H. Chen, N. Sutardja, R. Avizienis, A. Waterman,
B. Richards, P. Flatresse, E. Alon, K. Asanovic, and B. Nikolic, “A RISC-V vector processor with tightly-integrated switched-capacitor DC-DC converters in 28nm FD-SOI, year=2015, pages=C316-C317, month=June,,” in VLSI Circuits (VLSI Circuits), 2015 Symposium on.

9

[4] S. Pradeep and C. Laxmi, “Design and verification environment for amba axi protocol for soc integration.”
[5] ARM, “AMBA AXI and ACE protocol specification,” 2011, pp. 1–121.
[6] C. Ma, Z. Liu, and X. Ma, “Design and implementation of apb bridge based on amba 4.0,” in Consumer Electronics, Communications and Networks (CECNet), 2011 International Conference on, April 2011, pp. 193–196.

10

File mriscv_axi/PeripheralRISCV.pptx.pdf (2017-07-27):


# @onchipUIS

## RISC-V Community needs Peripheral Cores

Andrés Amaya, Javier Ardila, Héctor Gómez, Luis Rueda, Ckristian Durán, Rolando Torres, Juan Pablo Romero, Daniel Ramírez, Luis Chaparro and Elkim Roa

## Good to have an Open ISA. What about Peripheral?


- IP vendors have IP based on previous customer. Hard to get a glue-and-play that works for your SoC. → $$$
- There are some std, such as PHYs: USB, LPDDR, PCIe, AMBA
BUT
no for clocking circuitry, biasing, GPIO For instance a simple Power-on-Reset can hit your pocket, just because!
- Buses IP are out there but expensive. Why: Similar to compilers decades ago

## Can we do better? We might

## Agenda

## 1. Why we need more open-std silicon-HW?

2. IC Community can build up peripheral. Our case.
3. Suggestion and take away.

## Case 1: Receiving/Sending Data Bottleneck


- Compliance test suite - Functional model → UVM
Open-IP Bus | RISC-V core used | Provider | Repository | Functional Model | Silicon proven
SPI | Rocket/Open-V/ Epihany-V | Adapteva | github.com/adapteva | ✓ | ✓
I2C | Open-V/Pulp | Onchip/Pulp | github.com/onchipUIS | ✓ | ✓

AXI-4.0

APB-4.0

AHB-2.0

USB 2.0 PHY

USB 3.1 PHY

RapidIO

LPDDR3

## Suggestion: RISC-V Recommends

## Lot of circuits, lot of skills

PCB; RTL Code; ESD; Biasing; Data converters; Power; Integrity; Layout; PLL; Clock distribution; Signal Integrity; Verification; Sign-off

## - Don’t get your SoC-idea stuck just because you don’t have

regular IP.

- We need more standard Peripherals.
- Don’t reinvent the wheel. We need to join efforts.

## Take away

## Support us!


## https://www.crowdsupply.com/onchip/open-v

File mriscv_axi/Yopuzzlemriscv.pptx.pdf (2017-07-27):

Integrated Circuits and
Systems Group

Universidad Industrial de
Santander

## YoPuzzle: A mRISC-V development platform for next generations

Ckristian Duran, Luis Rueda, Giovany Castillo, Anderson Agudelo, Camilo Rojas, Luis Chaparro, Harry Hurtado, Rolando Torres, Juan Romero, Wilmer Ramirez,Hector Gomez, Hugo Hernandez, Jose Amaya and Elkim Roa

Team

We are a circuit design team NOT a computer architecture team. We can crack specs to RTL and to transistor level.

Over 10 tapeout chips. Analog and digital flow. 45nm, 65nm, 130nm, 180nm, 0.35um and 0.8um CMOS.

Graduate | students | with | industry | experience | from
Freescale, NXP and Samsung.

Alumni at Intel, Qualcomm, Freescale, NXP, Rambus, IDT and Semtech.


Project Goals

Initial :
An ARM-M0 to be used as on-chip test platform for high-speed interfaces. Test of high-speed flops and circuitry within a processor.

Mid:
A RISC-V core to be used for on-chip test platform.

Current:
A low-footprint RISC-V microcontroller alike EFM32 (Silicon Labs) and SAMD11 (Atmel) with USB low-speed PHY on-chip.

Inputs; Vscale (Z-scale); picorv32 (C. Wolf); AXI4-lite AHB-Lite APB Specs; SAR ADC 10-bit; DAC, PLL GPIO; Some crafted Scells; Modular- Human Verilog

Architecture

Executes RV32IM


32-bit 3-stage SIIO pipeline

AHB-Lite 3.0 and AXI-4
32-bit wide

IRQ handling
adapted from
picorv32. Timer

Implementation

Human-readable modular verilog for RV32I 1210 synthesizable LoC for AXI-4 based micro
8110 logic and 3426 logic cells using RVT lib
2613 buffering cells

AXI-4 lite 4.0 compliant? (hoping commercial VIP)

APB-bridge interface, SPI-AXI-4 interface

32 dual-port register file

GPIO and DAC-12-bit AXI-4 interface

Verification IP for AXI-4 to APB following UVM

Ring-VCO based PLL and SAR ADC 10-bit

SAR ADC

10-bit 10MHz


APB interface

IRQ enabled

Planned to be
fully synthesizable
→ pseudo synthesized


Chip

TSMC 130nm GP

I/O standard lib 2.5V

Regular VT cell lib

Tested from 10MHz
to 100MHz (wc SSLHH)

Taped-out in Oct. 2015

Core+interfaces area:
800μm x 480μm
CORE | SRAM 4kB

ADC

Dec. Caps

UVM Verification IP


Large effort on verification

Implemented VIP
testbenches for AXI-4
and APB peripheral
functionality

Post-synthesis,
post-PnR and
sign-off test
UVM modes

Still work going on.
We would like
to partner to get
proven VIP

Performance

| Z-SCALE | μRISC-V
ISA | RV32IM | RV32IM
Architecture | Single-Issue In-Order 3-stage | Single-Issue In-Order 3-stage
Process | TSMC 40nm GP | TSMC 130nm GP
Core area | 0.0098 mm² | 0.12 mm² !
Performance | 1.35 DMIPS/MHz | 0.32 DMIPS/MHz
Frequency | ~500MHz | 100MHz
Core Voltage | 1 V | 1.2 V
Dynamic Power | 1.8 μW/MHz | 19 μW/MHz !*

! Fully constrained clock and loads for SSLHH corner. Zero skew CTS. * Measured at 100MHz typical corner averaged from typical memory access
execution.

Summary

A RV32IM microcontroller-based with 10-bit ADC, DAC, timer and GPIO

Human-readable synthesizable verilog for core and AXI-4 lite, AHB lite, APB bridge and AXI-4-SPI interfaces

First effort for open source UVM VIP for RV32IM, AXI-4 lite, APB bridge

Future work on USB PHY LS interface, DMA channels, Watchdog timer, eNVM 1-poly ROM.

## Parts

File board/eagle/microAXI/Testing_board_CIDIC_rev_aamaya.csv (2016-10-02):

Qty | Value | Device | Package | Parts | Description | MF | MPN | OC_FARNELL | OC_NEWARK | PROD_ID | TP_SIGNAL_NAME | VALUE
1 |  | AUDIO-JACK_DIGIKEYSMD | STEREOJACK2.5MM_SMD | J1 | 3.5mm Audio Jack |  |  |  |  | CONN-10062
1 |  | JP1E | JP1 | JP10 | JUMPER
3 |  | JP2Q | JP2Q | JP4, JP11, JP17 | JUMPER
1 |  | JP2QE | JP2Q | JP8 | JUMPER
2 |  | JP3Q | JP3Q | JP13, JP15 | JUMPER
1 |  | JP3QE | JP3Q | JP16 | JUMPER
1 |  | JP6QE | JP6Q | JP3 | JUMPER
6 |  | LEDCHIPLED_0805 | CHIPLED_0805 | LED3, LED4, LED5, LED6, LED7, LED8 | LED
5 |  | LEDSML0805 | SML0805 | LED1, LED2, LED9, LED10, LED11 | LED
1 |  | MCP1700T-1202E/TTCT-ND | SOT-23 | D1 | MCP1700T-1202E/TTCT-ND
11 |  | PINHD-1X1 | 1X01 | JP18, JP19, JP20, JP21, JP22, JP23, JP24, JP25, JP26, JP27, JP30 | PIN HEADER
4 |  | PINHD-1X2 | 1X02 | JP5, JP12, JP28, JP29 | PIN HEADER
2 |  | PINHD-1X3 | 1X03 | JP7, JP14 | PIN HEADER
1 |  | PINHD-1X4 | 1X04 | JP2 | PIN HEADER
1 |  | PINHD-1X5 | 1X05 | JP9 | PIN HEADER
1 |  | PINHD-1X8 | 1X08 | JP6 | PIN HEADER
1 |  | PINHD-2X2 | 2X02 | JP1 | PIN HEADER
2 |  | R-TRIMM4G/J | RTRIM4G/J | R6, R27 | Trimm resistor
1 |  | USB-A-H | USB-A-H | X7 | USB Connectors
5 | 10-22uF | C-EUC0603 | C0603 | C1, C2, C3, C17, C29 | CAPACITOR, European symbol
2 | 100 | R-EU_R0603 | R0603 | R19, R28 | RESISTOR, European symbol
1 | 1000 | R-EU_R0603 | R0603 | R20 | RESISTOR, European symbol
10 | 100n | C-EUC0603 | C0603 | C4, C5, C6, C7, C8, C9, C11, C12, C35, C37 | CAPACITOR, European symbol
10 | 100nF | C-EUC0603 | C0603 | C14, C15, C16, C19, C21, C26, C28, C30, C40, C41 | CAPACITOR, European symbol
11 | 10k | R-EU_R0603 | R0603 | R3, R4, R5, R8, R16, R17, R22, R25, R26, R31, R32 | RESISTOR, European symbol
11 | 10u | C-EUC0603 | C0603 | C10, C13, C18, C24, C31, C32, C33, C34, C36, C38, C39 | CAPACITOR, European symbol
1 | 1300 | R-EU_R0603 | R0603 | R23 | RESISTOR, European symbol
8 | 1800 | R-EU_R0603 | R0603 | R1, R2, R7, R11, R12, R13, R14, R15 | RESISTOR, European symbol
3 | 1uF | C-EUC0603 | C0603 | C20, C25, C27 | CAPACITOR, European symbol
1 | 200k | R-EU_R0603 | R0603 | R9 | RESISTOR, European symbol
3 | 27k | R-EU_R0603 | R0603 | R18, R21, R24 | RESISTOR, European symbol
1 | 30MHZ-OSCILLATOR | 30MHZ-OSCILLATOR | 5X3.2 | U2 | Generic 5x3.2 Oscillator |  |  |  |  | XTAL-11986
2 | 4pF | C-EUC0603 | C0603 | C22, C23 | CAPACITOR, European symbol
1 | AD1580ARTZ | LM50 | SOT23 | IC2 | SOT-23 Single-Supply Centigrade Temperature Sensor
1 | ADA4940 | ADA4940 | SO8 | U$5
1 | ADP322 | ADP322 | LFCSP_LQ-16 | GND
5 | BU-SMA-V | BU-SMA-V | BU-SMA-V | X1, X2, X3, X4, X5 | FEMALE SMA CONNECTOR |  |  | unknown | unknown
1 | BUZZERNS | BUZZERNS | BUZZER-12MM-NS | SG1 | Buzzer 12mm
3 | CIDIC_AXI_UC_TEST_DIE | CIDIC_AXI_UC_TEST_DIE | CIDIC_AXI_UC_TEST_DIE | U$1, U$6, U$7
4 | CKN9104CT-NDS | CKN9104CT-NDS | SKHMPXE010 | S1, S2, S3, S4 | http://www.digikey.com/product-detail/en/c-k-components/PTS525SM15SMTR2-LFS/CKN9104CT-ND/1146923
1 | CY22150KFZXC | CY22150KFZXC | TSSOP16 | U$4
2 | JUMPERAVDD | SOLDERJUMPERROUND | SJ_ROUND | SJ1, SJ4 | Solder Jumper
1 | JUMPERDVDD | SOLDERJUMPERROUND | SJ_ROUND | SJ2 | Solder Jumper
1 | JUMPERLEVEL | SOLDERJUMPERROUND | SJ_ROUND | SJ3 | Solder Jumper
1 | LEVEL_SHIFTER_8 | LEVEL_SHIFTER_8 | TSSOP20 | U$3
1 | MAX4230 | MAX4230 | SC-70-5 | U1 | 310020013 |  | LMV321IDCKR |  |  |  |  | LMV321IDCKR-sc70-5
1 | MAX4234RU | MAX4234RU | TSSOP14 | IC4 | Precision Micropower, Low Noise CMOS, Rail-to-Rail Input/Output Operational Amplifiers | ALTERA CORPORATION | AD8609ARUZ | 1464994 | 59K6934
4 | PTR1B1,27 | PTR1B1,27 | B1,27 | TP_1.2, TP_1.2A, TP_2.5, TP_3.3 | TEST PIN
13 | TPTP08R | TPTP08R | TP08R | TP26, TP27, TP28, TP29, TP30, TP31, TP32, TP33, TP34, TP35, TP36, TP37, TP38 | Test pad
31 | TPTP20R | TPTP20R | TP20R | TP1, TP2, TP3, TP4, TP5, TP6, TP7, TP8, TP9, TP10, TP11, TP12, TP13, TP14, TP15, TP16, TP17, TP18, TP19, TP20, TP21, TP22, TP23, TP24, TP25, TP39, TP40, TP41, TP42, TP43, TP44 | Test pad

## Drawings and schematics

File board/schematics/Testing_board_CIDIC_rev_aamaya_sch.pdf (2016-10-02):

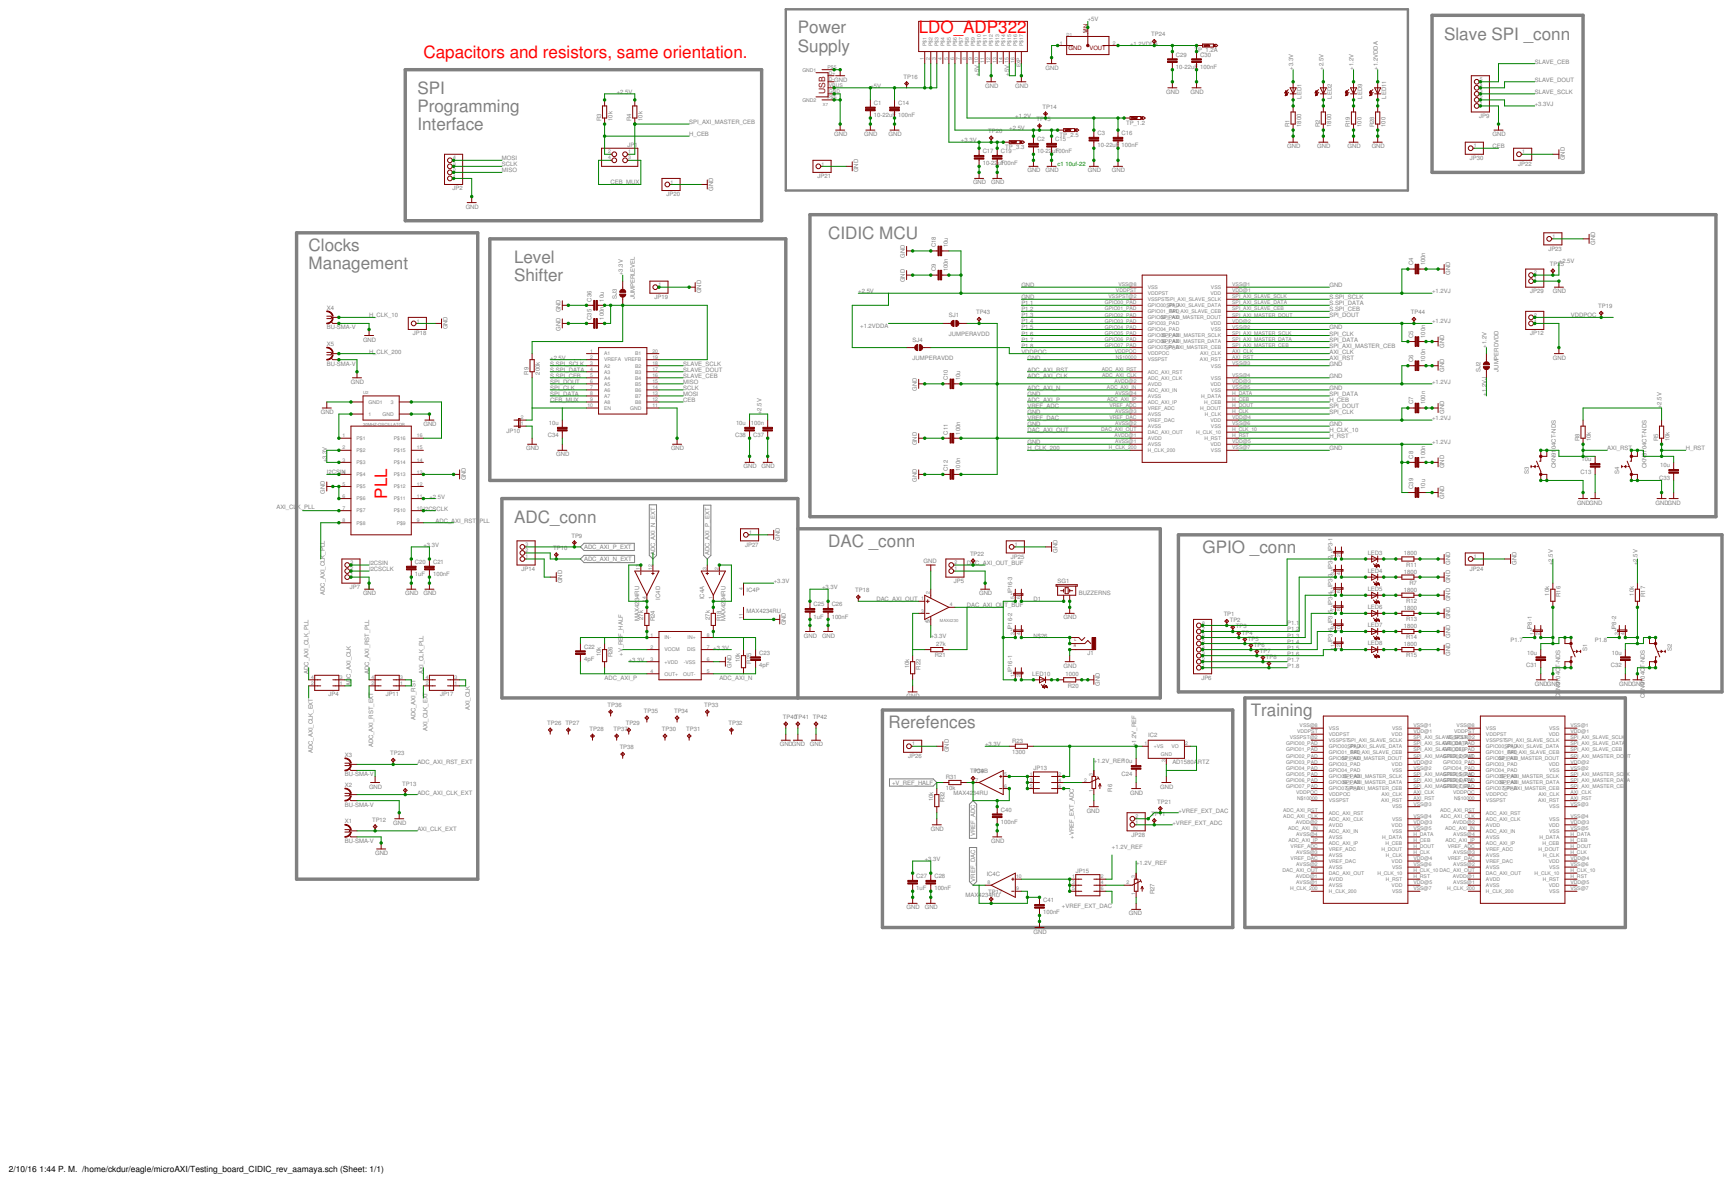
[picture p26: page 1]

Capacitors and resistors, same orientation.
SPI
Programming

GND GND GND GND GND

2/10/16 1:44 P. M. /home/ckdur/eagle/microAXI/Testing_board_CIDIC_rev_aamaya.sch (Sheet: 1/1)

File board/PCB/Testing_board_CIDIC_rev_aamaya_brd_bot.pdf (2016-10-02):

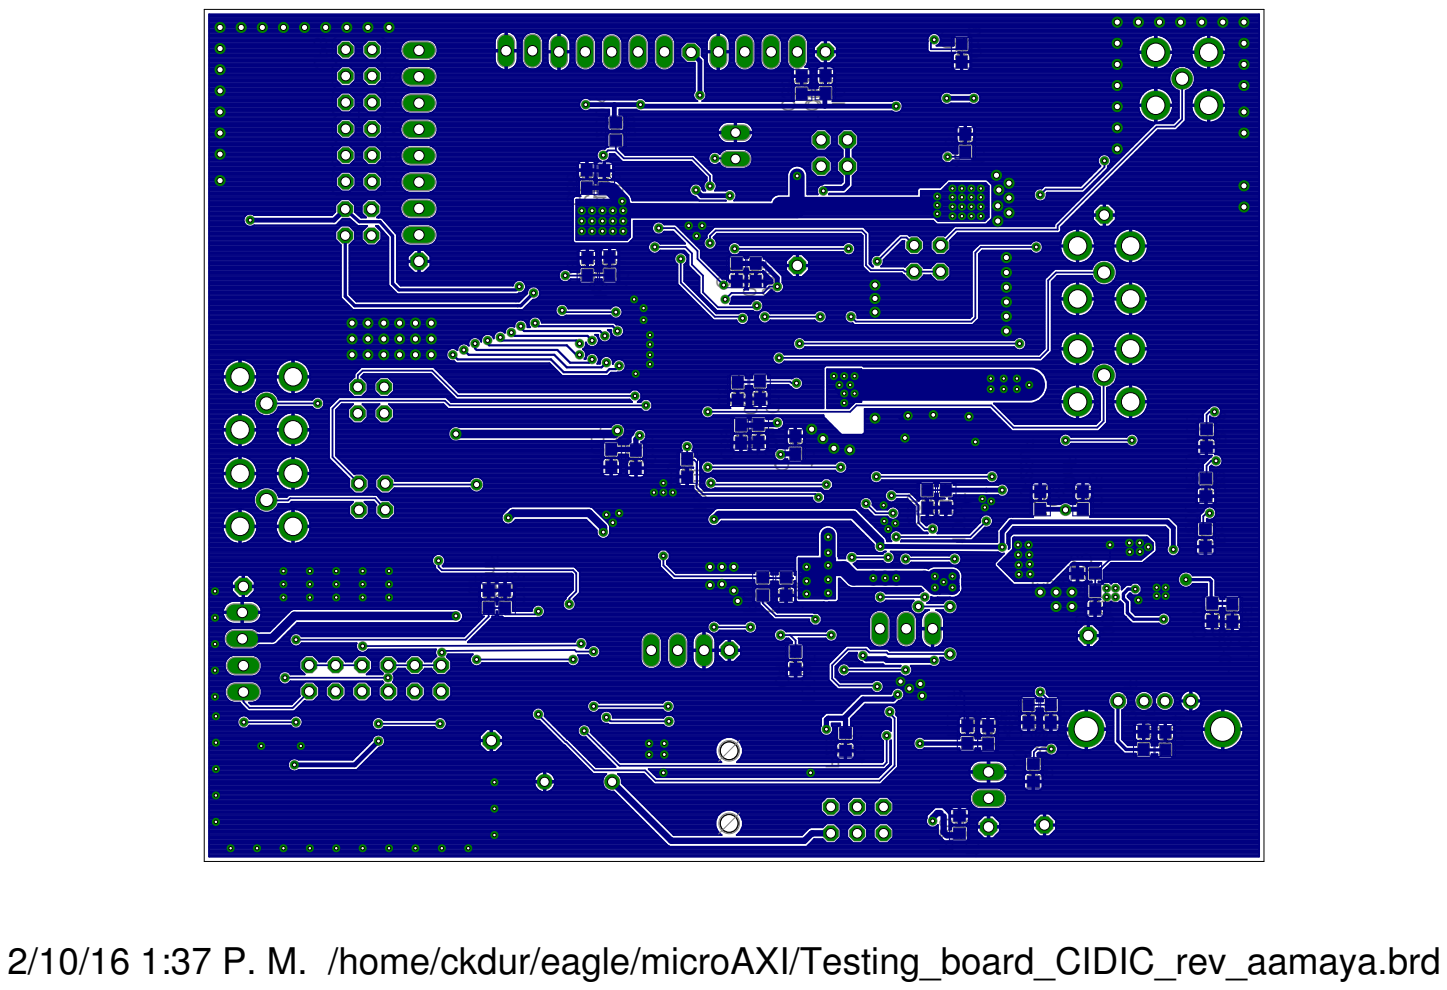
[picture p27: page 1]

2/10/16 1:37 P. M. /home/ckdur/eagle/microAXI/Testing_board_CIDIC_rev_aamaya.brd

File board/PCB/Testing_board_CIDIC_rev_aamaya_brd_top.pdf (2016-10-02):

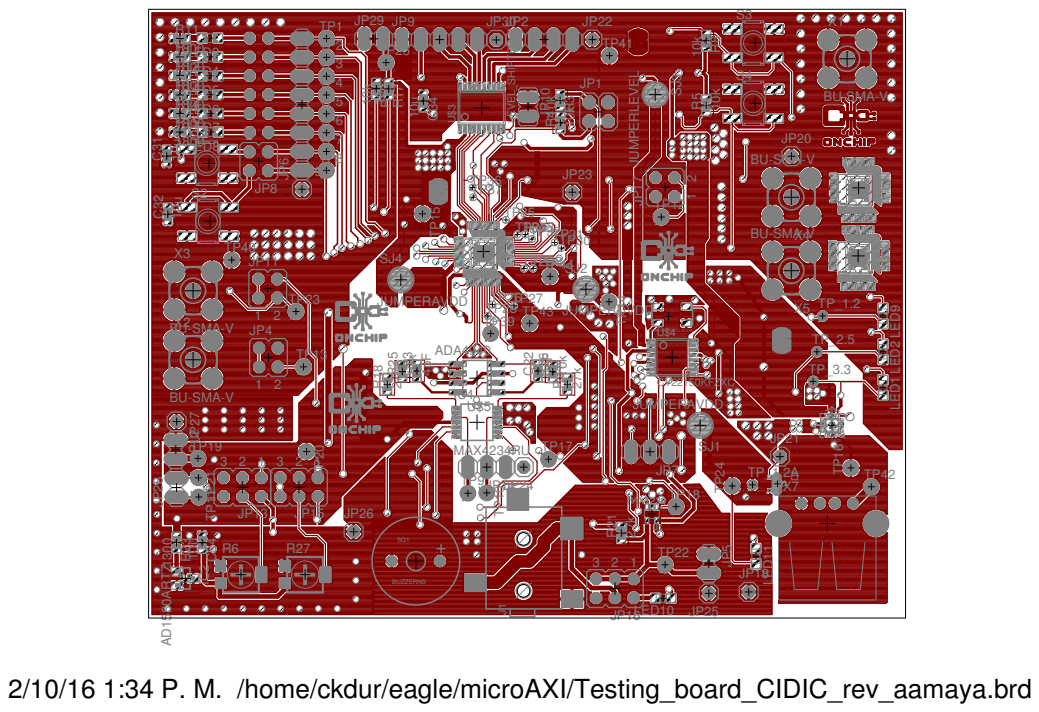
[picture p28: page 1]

2/10/16 1:34 P. M. /home/ckdur/eagle/microAXI/Testing_board_CIDIC_rev_aamaya.brd

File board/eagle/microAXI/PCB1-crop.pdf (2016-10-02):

## TP3 TP4 TP5 TP6 TP7 TP8

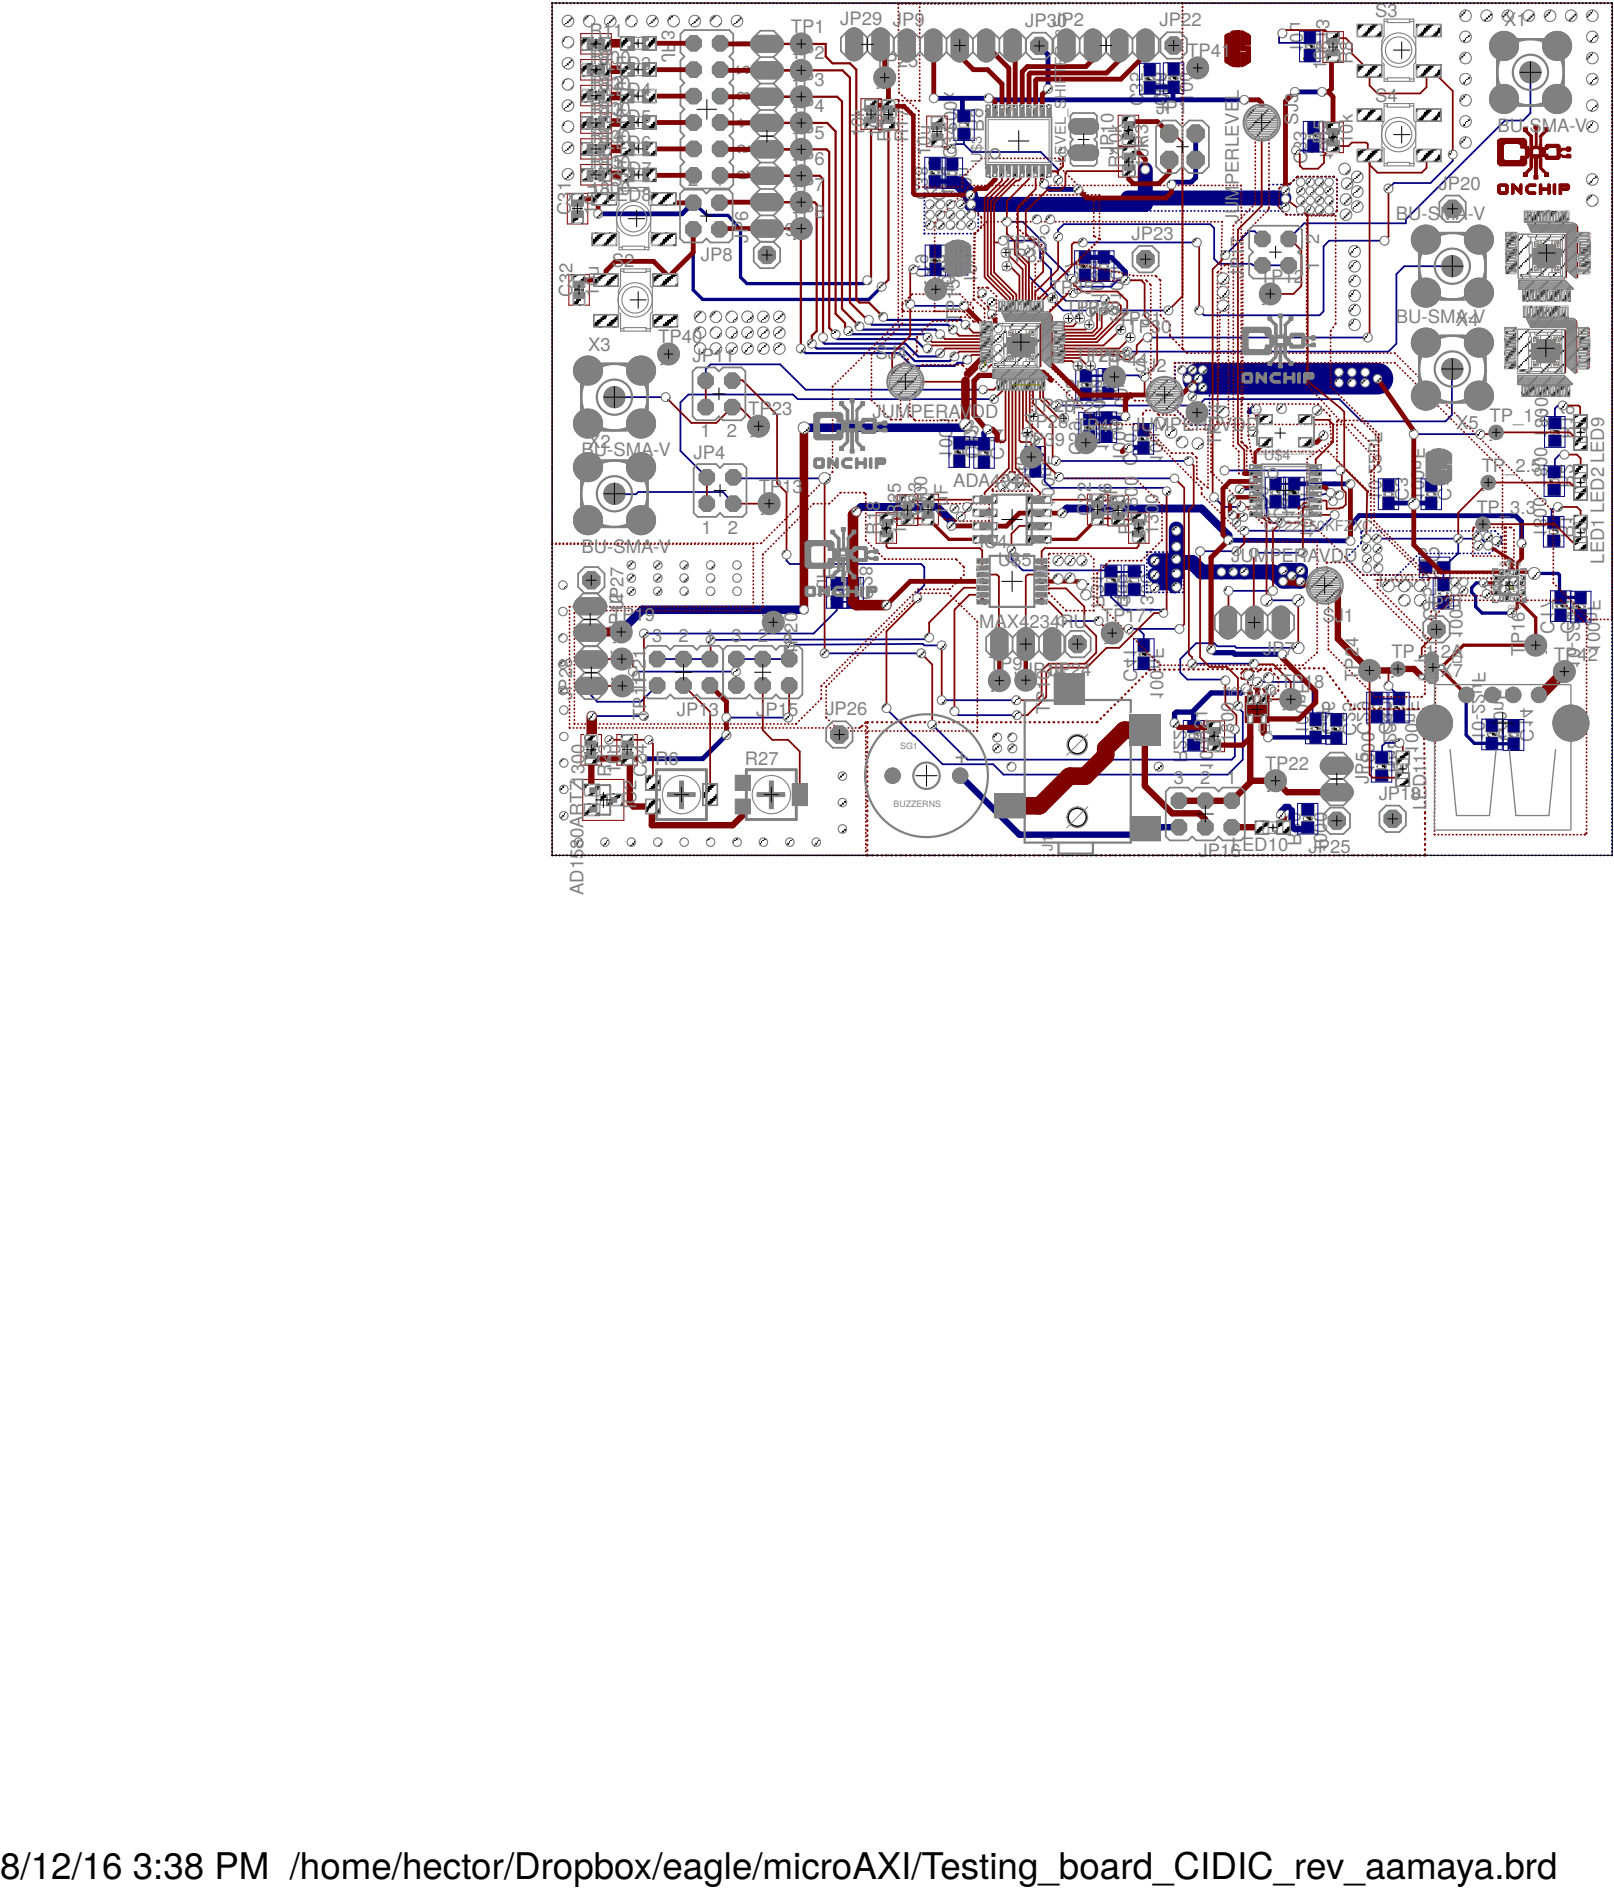
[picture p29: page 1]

8/12/16 3:38 PM /home/hector/Dropbox/eagle/microAXI/Testing_board_CIDIC_rev_aamaya.brd

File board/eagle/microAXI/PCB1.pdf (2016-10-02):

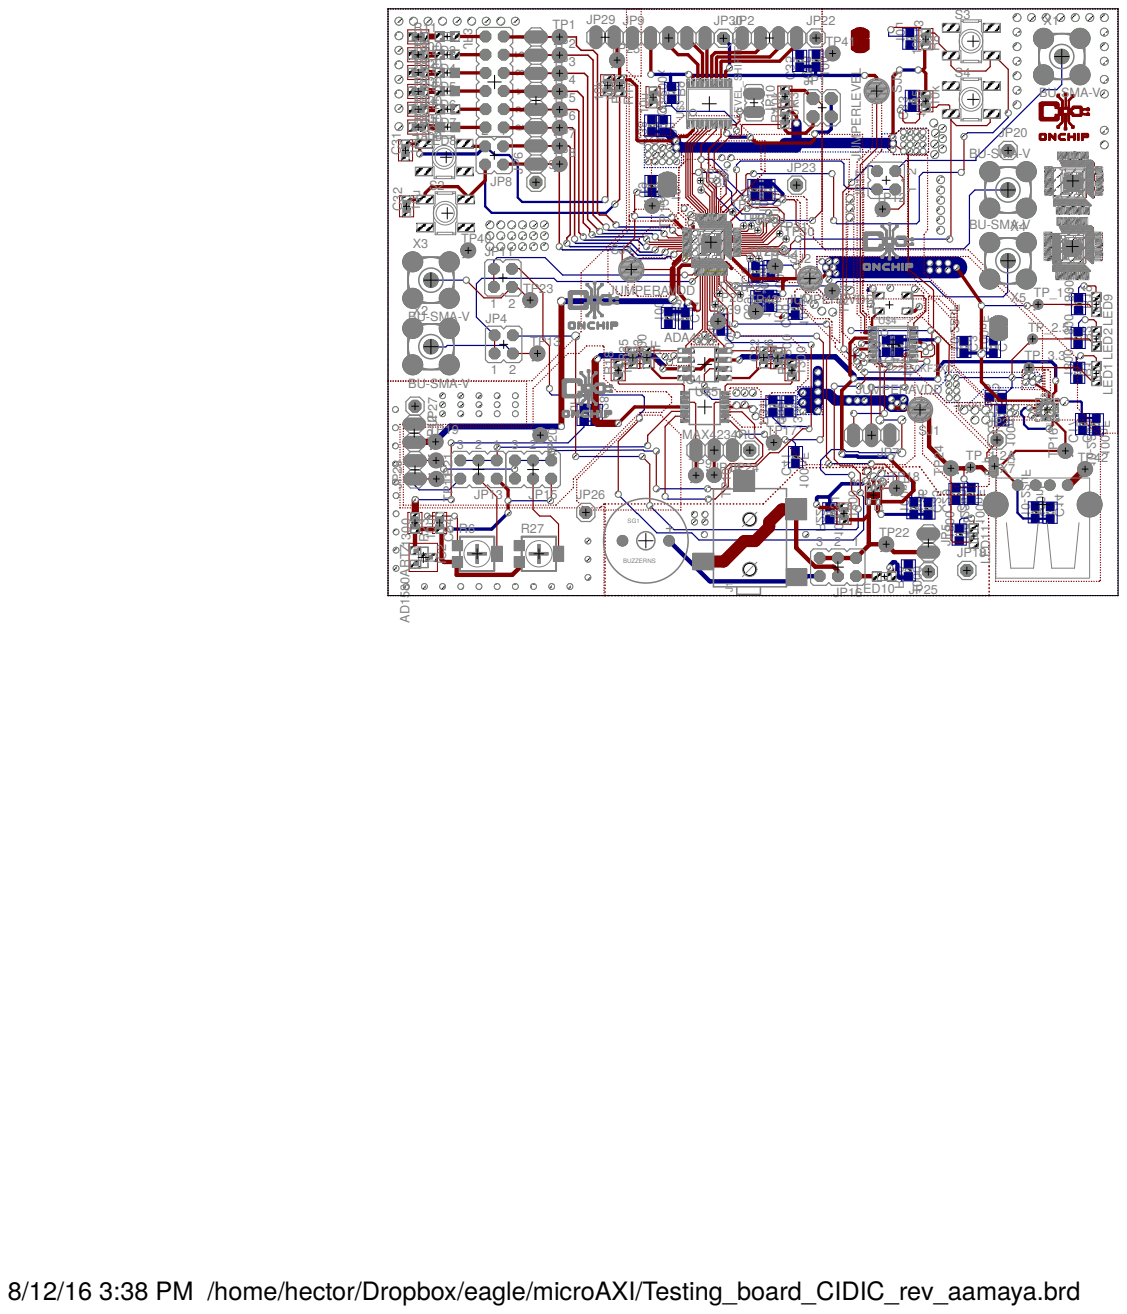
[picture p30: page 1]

8/12/16 3:38 PM /home/hector/Dropbox/eagle/microAXI/Testing_board_CIDIC_rev_aamaya.brd

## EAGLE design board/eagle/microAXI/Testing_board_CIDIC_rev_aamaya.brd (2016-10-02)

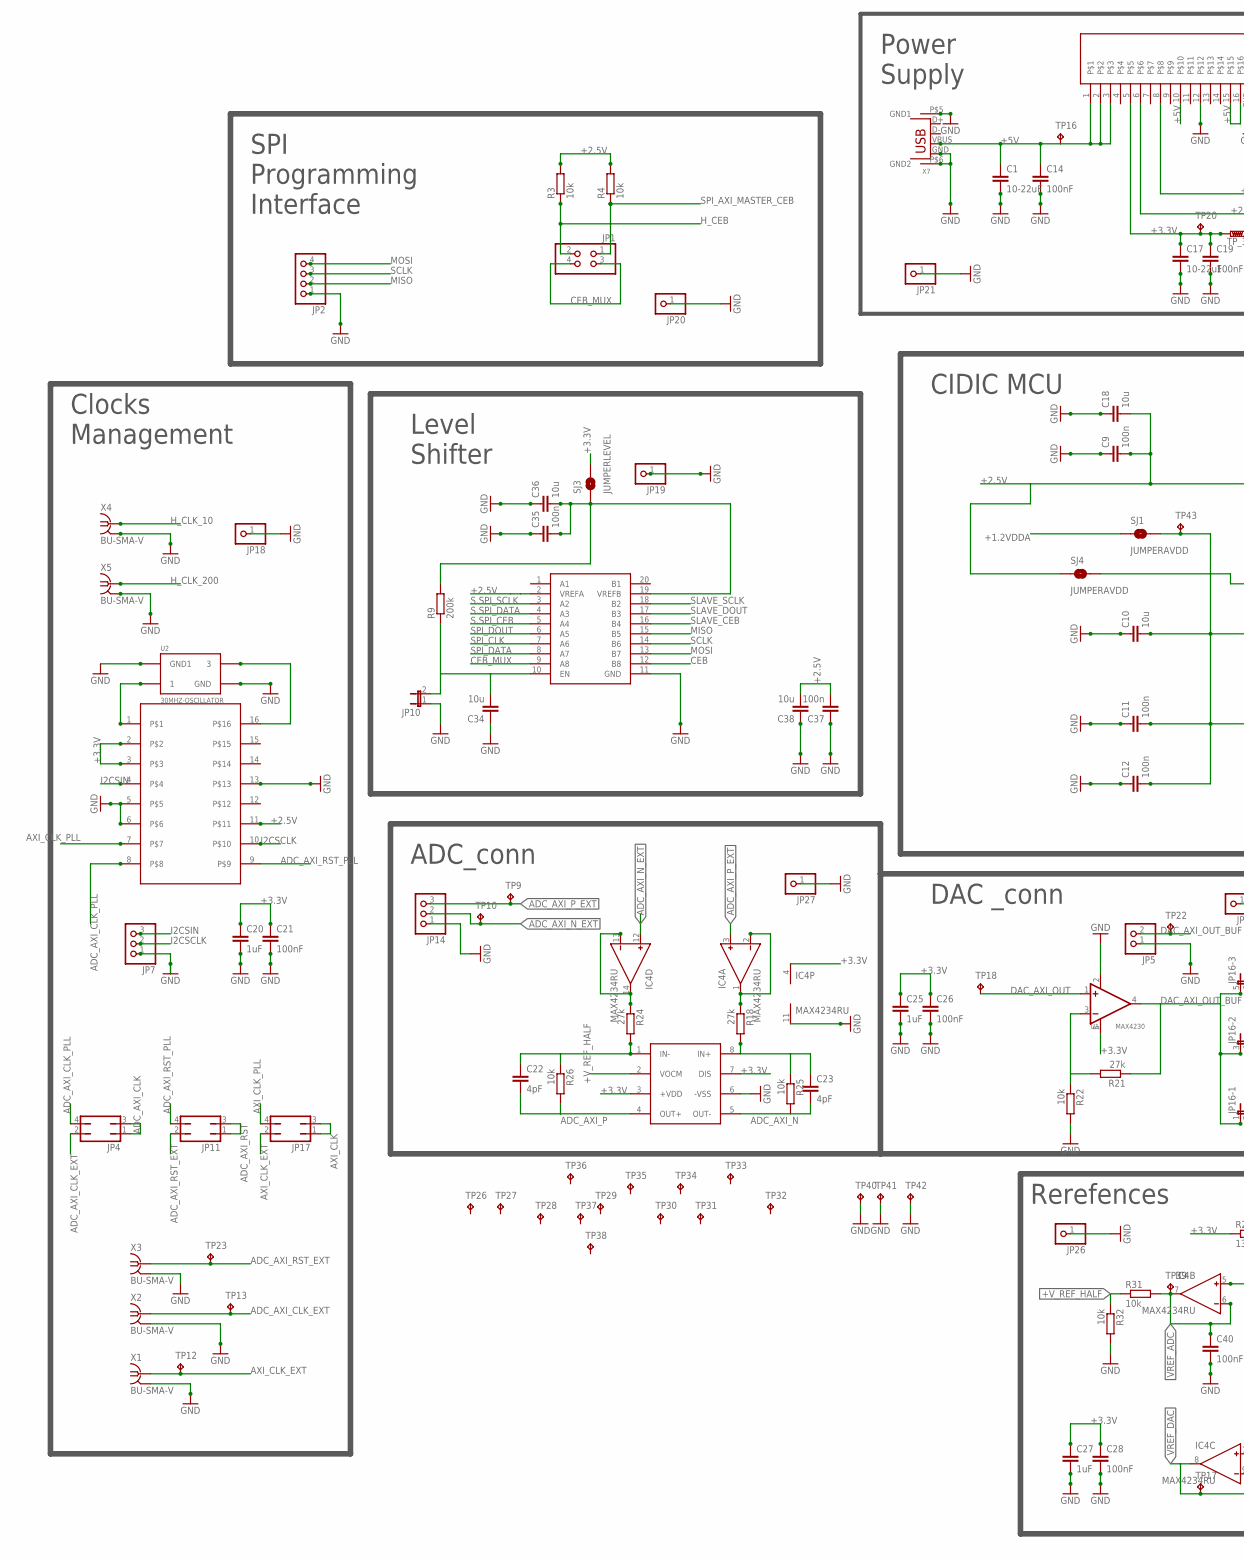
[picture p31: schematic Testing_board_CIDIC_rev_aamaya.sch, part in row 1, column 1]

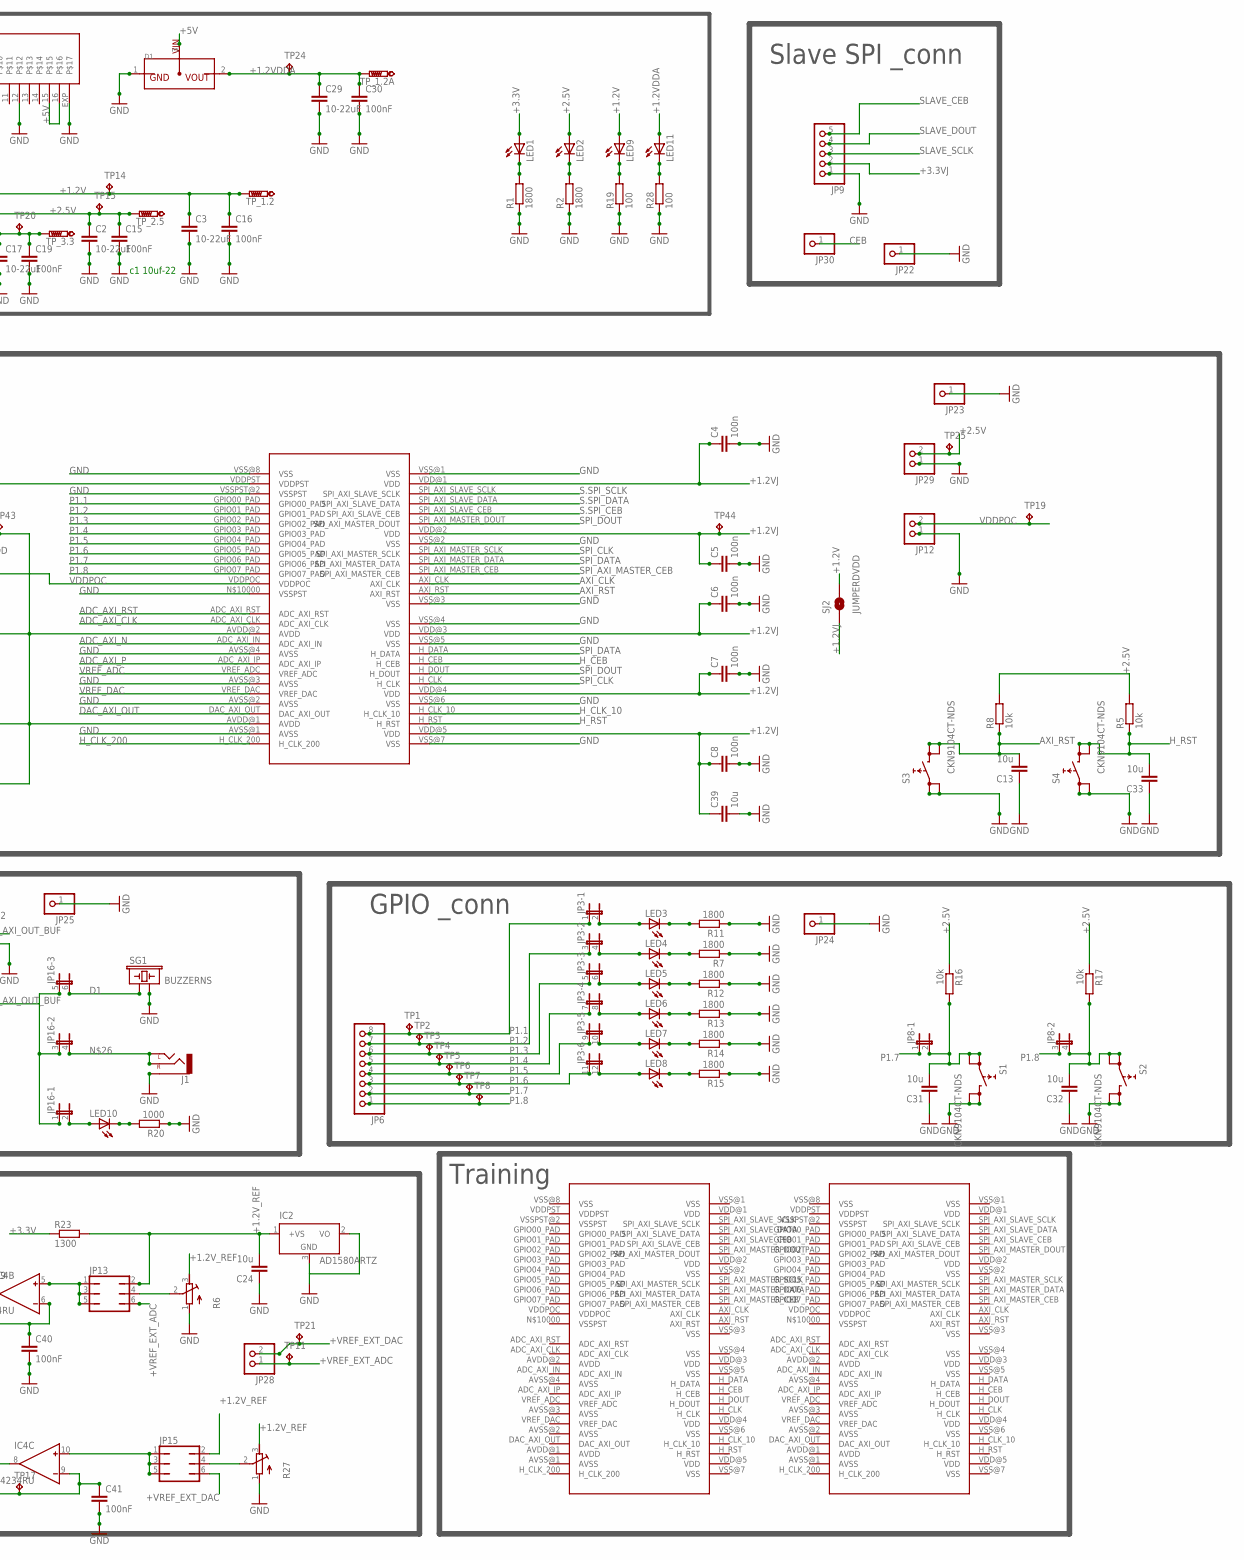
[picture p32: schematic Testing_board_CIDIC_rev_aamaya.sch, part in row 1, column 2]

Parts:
C1, C2, C3, C17, C29: 10-22uF; C0603
C4, C5, C6, C7, C8, C9, C11, C12, C35, C37: 100n; C0603
C10, C13, C18, C24, C31, C32, C33, C34, C36, C38, C39: 10u; C0603
C14, C15, C16, C19, C21, C26, C28, C30, C40, C41: 100nF; C0603
C20, C25, C27: 1uF; C0603
C22, C23: 4pF; C0603
D1: MCP1700T-1202E/TTCT-ND; SOT-23
GND: ADP322; LFCSP_LQ-16
IC2: AD1580ARTZ; SOT23
IC4: MAX4234RU; TSSOP14
J1: AUDIO-JACK_DIGIKEYSMD; STEREOJACK2.5MM_SMD
JP1: PINHD-2X2; 2X02
JP2: PINHD-1X4; 1X04
JP3: JP6QE; JP6Q
JP4, JP11, JP17: JP2Q
JP5, JP12, JP28, JP29: PINHD-1X2; 1X02
JP6: PINHD-1X8; 1X08
JP7, JP14: PINHD-1X3; 1X03
JP8: JP2QE; JP2Q
JP9: PINHD-1X5; 1X05
JP10: JP1E; JP1
JP13, JP15: JP3Q
JP16: JP3QE; JP3Q
JP18, JP19, JP20, JP21, JP22, JP23, JP24, JP25, JP26, JP27, JP30: PINHD-1X1; 1X01
LED1, LED2, LED9, LED10, LED11: LEDSML0805; SML0805
LED3, LED4, LED5, LED6, LED7, LED8: LEDCHIPLED_0805; CHIPLED_0805
R1, R2, R7, R11, R12, R13, R14, R15: 1800; R0603
R3, R4, R5, R8, R16, R17, R22, R25, R26, R31, R32: 10k; R0603
R6, R27: R-TRIMM4G/J; RTRIM4G/J
R9: 200k; R0603
R18, R21, R24: 27k; R0603
R19, R28: 100; R0603
R20: 1000; R0603
R23: 1300; R0603
S1, S2, S3, S4: CKN9104CT-NDS; SKHMPXE010
SG1: BUZZERNS; BUZZER-12MM-NS
SJ1, SJ4: JUMPERAVDD; SJ_ROUND
SJ2: JUMPERDVDD; SJ_ROUND
SJ3: JUMPERLEVEL; SJ_ROUND
TP1, TP2, TP3, TP4, TP5, TP6, TP7, TP8, TP9, TP10, TP11, TP12, TP13, TP14, TP15, TP16, TP17, TP18, TP19, TP20, TP21, TP22, TP23, TP24, TP25, TP39, TP40, TP41, TP42, TP43, TP44: TPTP20R; TP20R
TP26, TP27, TP28, TP29, TP30, TP31, TP32, TP33, TP34, TP35, TP36, TP37, TP38: TPTP08R; TP08R
TP_1.2, TP_1.2A, TP_2.5, TP_3.3: PTR1B1,27; B1,27
U1: MAX4230; SC-70-5
U2: 30MHZ-OSCILLATOR; 5X3.2
U$1, U$6, U$7: CIDIC_AXI_UC_TEST_DIE
U$3: LEVEL_SHIFTER_8; TSSOP20
U$4: CY22150KFZXC; TSSOP16
U$5: ADA4940; SO8
X1, X2, X3, X4, X5: BU-SMA-V
X7: USB-A-H

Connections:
+1.2V: C3.1, C16.1, GND.8, LED9.A, SJ2.2, TP14.TP, TP_1.2.TP
+1.2VDDA: C29.1, C30.1, D1.2 (VOUT), LED11.A, SJ1.1, TP24.TP, TP_1.2A.TP
+1.2VJ: C4.1, C5.1, C6.1, C7.1, C8.1, C39.1, SJ2.1, TP44.TP, U$1.VDD@1 (VDD), U$1.VDD@2 (VDD), U$1.VDD@3 (VDD), U$1.VDD@4 (VDD), U$1.VDD@5 (VDD)
+1.2V_REF: C24.2, IC2.1 (+VS), JP13.2, JP15.2, R6.3 (E), R23.2, R27.3 (E)
+2.5V: C2.1, C9.2, C15.1, C18.2, C37.2, C38.2, GND.6, JP29.2, LED2.A, R3.2, R4.2, R5.2, R8.2, R16.1, R17.1, SJ4.1, TP15.TP, TP25.TP, TP_2.5.TP, U$1.VDDPST, U$3.2 (VREFA), U$4.11
+3.3V: C17.1, C19.1, C20.1, C21.1, C25.1, C26.1, C27.1, C28.1, GND.5, IC4.4 (V+), LED1.A, R23.1, SJ3.2, TP20.TP, TP_3.3.TP, U1.5 (V+), U$4.2, U$4.3, U$5.3 (+VDD), U$5.7 (DIS)
+3.3VJ: C35.2, C36.2, JP9.2, R9.2, SJ3.1, U$3.19 (VREFB)
+5V: C1.1, C14.1, D1.3 (VIN), GND.1, GND.2, GND.3, GND.10, GND.15, GND.16, TP16.TP, X7.VBUS
+VREF_EXT_ADC: JP13.6, JP28.1, TP11.TP
+VREF_EXT_DAC: JP15.6, JP28.2, TP21.TP
+V_REF_HALF: R31.1, R32.1, U$5.2 (VOCM)
ADC_AXI_CLK: JP4.1, JP4.3, U$1.ADC_AXI_CLK
ADC_AXI_CLK_EXT: JP4.2, TP13.TP, X2.1
ADC_AXI_CLK_PLL: JP4.4, U$4.8
ADC_AXI_N: C23.2, R25.2, U$1.ADC_AXI_IN, U$5.5 (OUT-)
ADC_AXI_N_EXT: IC4.12 (IN+), JP14.2, TP10.TP
ADC_AXI_P: C22.2, R26.2, U$1.ADC_AXI_IP, U$5.4 (OUT+)
ADC_AXI_P_EXT: IC4.3 (IN+), JP14.3, TP9.TP
ADC_AXI_RST: JP11.1, JP11.3, U$1.ADC_AXI_RST
ADC_AXI_RST_EXT: JP11.2, TP23.TP, X3.1
ADC_AXI_RST_PLL: JP11.4, U$4.9
AXI_CLK: JP17.1, JP17.3, U$1.AXI_CLK
AXI_CLK_EXT: JP17.2, TP12.TP, X1.1
AXI_CLK_PLL: JP17.4, U$4.7
AXI_RST: C13.2, R8.1, S3.3 (2.1), S3.4 (2.2), U$1.AXI_RST
CEB: JP30.1, U$3.12 (B8)
CEB_MUX: JP1.3, JP1.4, U$3.9 (A8)
D1: JP16.6 (2), SG1.+ (1)
D3: JP16.2, LED10.A
DAC_AXI_OUT: TP18.TP, U1.1 (IN+), U$1.DAC_AXI_OUT
DAC_AXI_OUT_BUF: JP5.2, JP16.1, JP16.3 (1), JP16.5 (1), R21.1, TP22.TP, U1.4 (OUT)
GND: C1.2, C2.2, C3.2, C4.2, C5.2, C6.2, C7.2, C8.2, C9.1, C10.1, C11.1, C12.1, C13.1, C14.2, C15.2, C16.2, C17.2, C18.1, C19.2, C20.2, C21.2, C24.1, C25.2, C26.2, C27.2, C28.2, C29.2, C30.2, C31.1, C32.1, C33.1, C34.1, C35.1, C36.1, C37.1, C38.1, C39.2, C40.2, C41.2, D1.1 (GND), GND.12, GND.EXP, IC2.2 (VO), IC2.3 (GND), IC4.11 (V-), J1.1 (SLEEVE), JP2.1, JP5.1, JP7.1, JP9.1, JP10.1, JP12.1, JP14.1, JP18.1, JP19.1, JP20.1, JP21.1, JP22.1, JP23.1, JP24.1, JP25.1, JP26.1, JP27.1, JP29.1, R1.1, R2.1, R6.1 (A), R7.1, R11.1, R12.1, R13.1, R14.1, R15.1, R19.1, R20.1, R22.2, R27.1 (A), R28.1, R32.2, S1.3 (2.1), S1.4 (2.2), S2.3 (2.1), S2.4 (2.2), S3.1 (1.1), S3.2 (1.2), S4.1 (1.1), S4.2 (1.2), SG1.- (2), TP40.TP, TP41.TP, TP42.TP, U1.2 (V-), U2.2 (GND), U2.4 (GND1), U$1.AVSS@1 (AVSS), U$1.AVSS@2 (AVSS), U$1.AVSS@3 (AVSS), U$1.AVSS@4 (AVSS), U$1.N$10000 (VSSPST), U$1.VSS@1 (VSS), U$1.VSS@2 (VSS), U$1.VSS@3 (VSS), U$1.VSS@4 (VSS), U$1.VSS@5 (VSS), U$1.VSS@6 (VSS), U$1.VSS@7 (VSS), U$1.VSS@8 (VSS), U$1.VSSPST@2 (VSSPST), U$3.11 (GND), U$4.5, U$4.6, U$4.13, U$5.6 (-VSS), X1.2, X1.3 (2), X1.4 (2), X1.5 (2), X2.2, X2.3 (2), X2.4 (2), X2.5 (2), X3.2, X3.3 (2), X3.4 (2), X3.5 (2), X4.2, X4.3 (2), X4.4 (2), X4.5 (2), X5.2, X5.3 (2), X5.4 (2), X5.5 (2), X7.GND, X7.P$5 (GND1), X7.P$6 (GND2)
H_CEB: JP1.2, R3.1, U$1.H_CEB
H_CLK_10: U$1.H_CLK_10, X4.1
H_CLK_200: U$1.H_CLK_200, X5.1
H_RST: C33.2, R5.1, S4.3 (2.1), S4.4 (2.2), U$1.H_RST
I2CSCLK: JP7.2, U$4.10
I2CSIN: JP7.3, U$4.4
JV12A: C10.2, C11.2, C12.2, SJ1.2, TP43.TP, U$1.AVDD@1 (AVDD), U$1.AVDD@2 (AVDD)
MISO: JP2.2, U$3.15 (B5)
MOSI: JP2.4, U$3.13 (B7)
unnamed: U2.1, U$4.1
unnamed: LED1.C, R1.2
unnamed: LED2.C, R2.2
unnamed: C22.1, R24.2, R26.1, U$5.1 (IN-)
unnamed: LED9.C, R19.2
unnamed: C31.2, JP8.2, R16.2, S1.1 (1.1), S1.2 (1.2)
unnamed: C32.2, JP8.4 (2), R17.2, S2.1 (1.1), S2.2 (1.2)
unnamed: C23.1, R18.2, R25.1, U$5.8 (IN+)
unnamed: U2.3, U$4.16
unnamed: JP13.4, R6.2 (S)
unnamed: LED11.C, R28.2
unnamed: IC4.13 (IN-), IC4.14 (OUT), R24.1
unnamed: LED4.C, R7.2
unnamed: JP3.4 (2), LED4.A
unnamed: JP3.6 (2), LED5.A
unnamed: JP3.8 (2), LED6.A
unnamed: JP3.10 (2), LED7.A
unnamed: JP3.2, LED3.A
unnamed: LED3.C, R11.2
unnamed: JP3.12 (2), LED8.A
unnamed: LED5.C, R12.2
unnamed: LED6.C, R13.2
unnamed: LED7.C, R14.2
unnamed: LED8.C, R15.2
unnamed: J1.2 (LEFT), J1.3 (RIGHT), JP16.4 (2)
unnamed: IC4.1 (OUT), IC4.2 (IN-), R18.1
unnamed: R21.2, R22.1, U1.3 (IN-)
unnamed: LED10.C, R20.2
unnamed: IC4.10 (IN+), JP15.1, JP15.3, JP15.5
unnamed: IC4.5 (IN+), JP13.1, JP13.3, JP13.5
unnamed: JP15.4, R27.2 (S)
unnamed: C34.2, JP10.2, R9.1, U$3.10 (EN)
P1.1: JP3.1, JP6.8, TP1.TP, U$1.GPIO00_PAD
P1.2: JP3.3 (1), JP6.7, TP2.TP, U$1.GPIO01_PAD
P1.3: JP3.5 (1), JP6.6, TP3.TP, U$1.GPIO02_PAD
P1.4: JP3.7 (1), JP6.5, TP4.TP, U$1.GPIO03_PAD
P1.5: JP3.9 (1), JP6.4, TP5.TP, U$1.GPIO04_PAD
P1.6: JP3.11 (1), JP6.3, TP6.TP, U$1.GPIO05_PAD
P1.7: JP6.2, JP8.1, TP7.TP, U$1.GPIO06_PAD
P1.8: JP6.1, JP8.3 (1), TP8.TP, U$1.GPIO07_PAD
S.SPI_CEB: U$1.SPI_AXI_SLAVE_CEB, U$3.5 (A4)
S.SPI_DATA: U$1.SPI_AXI_SLAVE_DATA, U$3.4 (A3)
S.SPI_SCLK: U$1.SPI_AXI_SLAVE_SCLK, U$3.3 (A2)
SCLK: JP2.3, U$3.14 (B6)
SLAVE_CEB: JP9.5, U$3.16 (B4)
SLAVE_DOUT: JP9.4, U$3.17 (B3)
SLAVE_SCLK: JP9.3, U$3.18 (B2)
SPI_AXI_MASTER_CEB: JP1.1, R4.1, U$1.SPI_AXI_MASTER_CEB
SPI_CLK: U$1.H_CLK, U$1.SPI_AXI_MASTER_SCLK, U$3.7 (A6)
SPI_DATA: U$1.H_DATA, U$1.SPI_AXI_MASTER_DATA, U$3.8 (A7)
SPI_DOUT: U$1.H_DOUT, U$1.SPI_AXI_MASTER_DOUT, U$3.6 (A5)
VDDPOC: JP12.2, SJ4.2, TP19.TP, U$1.VDDPOC
VREF_ADC: C40.1, IC4.6 (IN-), IC4.7 (OUT), R31.2, TP39.TP, U$1.VREF_ADC
VREF_DAC: C41.1, IC4.8 (OUT), IC4.9 (IN-), TP17.TP, U$1.VREF_DAC

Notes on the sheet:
Power Supply
SPI Programming Interface
Clocks Management
ADC_conn
DAC _conn
GPIO _conn
Slave SPI _conn
Level Shifter
CIDIC MCU
Rerefences
c1 10uf-22
Training

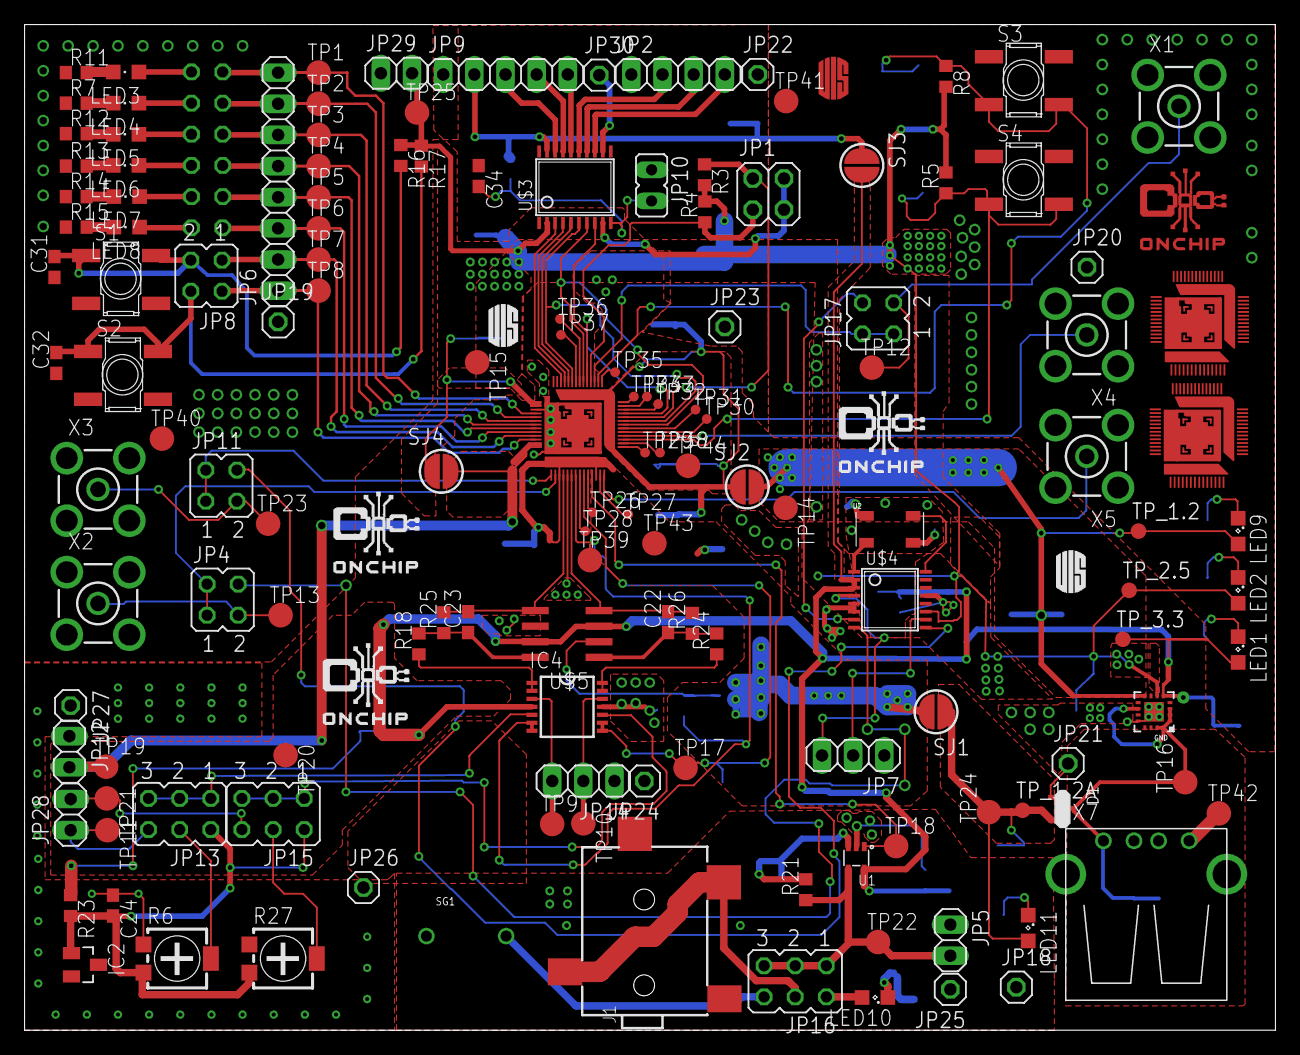
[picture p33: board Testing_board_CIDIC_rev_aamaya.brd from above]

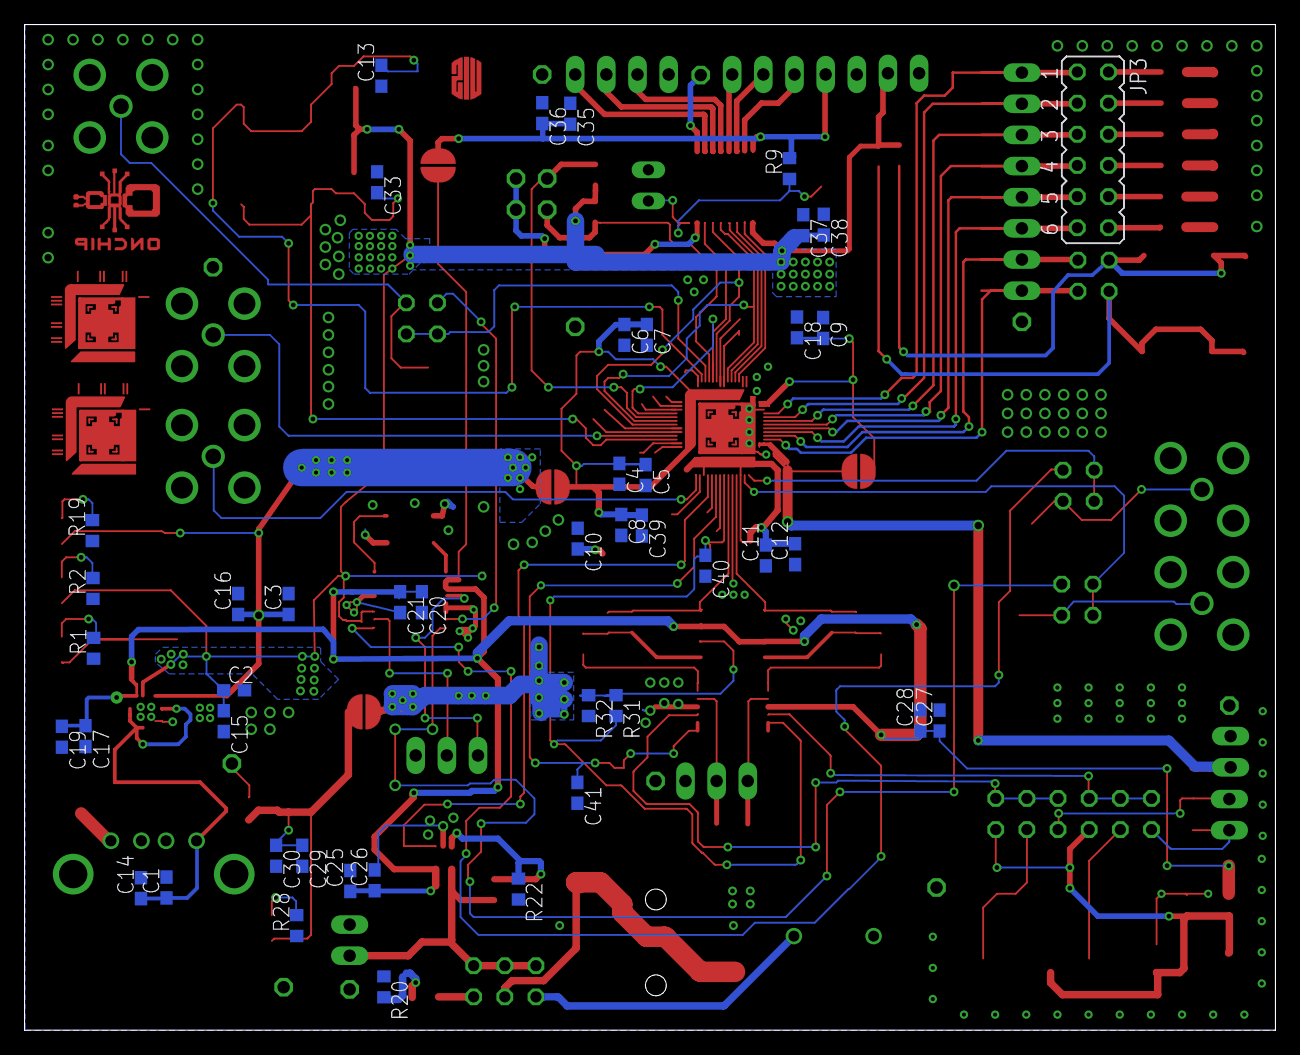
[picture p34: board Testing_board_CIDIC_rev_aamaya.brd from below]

Board: 2 copper layers, 102.0 x 82.0 mm, 187 parts (45 on the bottom side), 95 nets.

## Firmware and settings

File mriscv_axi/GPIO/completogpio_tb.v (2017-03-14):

`timescale 1ns / 1ps



module completogpio_tb;

	// Inputs
	reg [31:0] WAddress;
	reg [31:0] Wdata;
	reg AWvalid;
	reg [7:0] pindata;
	reg [31:0] RAddress;
	reg Wvalid;
	reg clock;
	reg ARvalid;
	reg reset;
	reg Rready;
	reg Bready;
	reg [3:0 ]strobe;

	// Outputs
	wire [7:0] DSE;
	wire ARready;
	wire Rvalid;
	wire AWready;
	wire Wready;
	wire Bvalid;
	wire [7:0] Rx;
	wire [7:0] datanw;
	wire [7:0] Tx;
	wire [31:0] Rdata;

	// Instantiate the Unit Under Test (UUT)
	completogpio uut (
		.WAddress(WAddress), 
		.Wdata(Wdata), 
		.AWvalid(AWvalid), 
		.pindata(pindata), 
		.RAddress(RAddress), 
		.Wvalid(Wvalid), 
		.clock(clock), 
		.ARvalid(ARvalid), 
		.reset(reset), 
		.Rready(Rready), 
		.Bready(Bready), 
		.DSE(DSE), 
		.ARready(ARready), 
		.Rvalid(Rvalid), 
		.AWready(AWready), 
		.Wready(Wready), 
		.Bvalid(Bvalid), 
		.Rx(Rx), 
		.datanw(datanw), 
		.Tx(Tx), 
		.Rdata(Rdata)
	);

	always #1 clock=~clock;
	initial begin
		// Initialize Inputs
		WAddress = 0;
		Wdata = 0;
		AWvalid = 0;
		pindata = 8'd0;
		RAddress = 0;
		Wvalid = 0;
		clock = 0;
		ARvalid = 0;
		reset = 0;
		Rready = 0;
		Bready = 0;
		

		// escritura
		#2;
		reset=1;
		Rready=0;
		WAddress=32'hEFA;
		Wdata=32'hABCDEFFF;
		pindata = 8'b10101010;
		RAddress=32'd88393348;
		AWvalid=1;
		#1;
		Wvalid=1;
		#2.5;
		Wvalid=0;		
		#2.5;
		AWvalid=0;
		Bready=1;
		
		#2.5;
		reset=0;
		Bready=0;		
		// lectura
		
		#10;
		reset=1;
		
		ARvalid=1;
		#2.5;
		Rready=1;
		ARvalid=0;
		#2.0;
		Rready=0;
		
		
		
		#4;
		reset=0;
		// escritura
		#10;
		reset=1;
		Rready=0;
		WAddress=32'hEFA6;
		Wdata=32'hABCDEFF1;
		pindata = 8'b10101010;
		RAddress=32'd88393348;
		AWvalid=1;
		#1;
		Wvalid=1;
		#8;
		Wvalid=0;		
		#9;
		AWvalid=0;
		Bready=1;
		
		#9;
		reset=0;	
		Bready=0;
		
		// lectura
		
		#10;
		reset=1;
		ARvalid=1;
		#6;
		Rready=1;
		ARvalid=0;
		
		#4;
		reset=0;
		Rready=0;
		#2;
		reset=1;
		$finish;
/*				// escritura
		#100;
		reset=1;
		Rready=0;
		WAddress=32'hEFA;
		Wdata=32'hABCDEFFF;
		pindata = 8'b10101010;
		RAddress=32'd88393348;
		AWvalid=1;
		#10;
		Wvalid=1;
		#25;
		Wvalid=0;		
		#25;
		AWvalid=0;
		Bready=1;
		
		#25;
		reset=0;		
		// lectura
		
		#100;
		reset=1;
		Bready=0;
		ARvalid=1;
		#25;
		Rready=1;
		ARvalid=0;
		
		
		
		
		#20;
		reset=0;
		Rready=0;*/
		/*// escritura
		#100;
		reset=1;
		Rready=0;
		WAddress=32'hEFA6;
		Wdata=32'hABCDEFF1;
		pindata = 8'b10101010;
		RAddress=32'd88393348;
		AWvalid=1;
		#10;
		Wvalid=1;
		#80;
		Wvalid=0;		
		#90;
		AWvalid=0;
		Bready=1;
		
		#90;
		reset=0;	
		
		// lectura
		
		#100;
		reset=1;
		Bready=0;
		ARvalid=1;
		#60;
		Rready=1;
		ARvalid=0;
		
		#60;
		reset=0;
		Rready=0;*/
		
		// Add stimulus here

	end
      
endmodule

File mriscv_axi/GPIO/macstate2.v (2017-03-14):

`timescale 1ns / 1ps

//////////////////////////////////////////////////////////////////////////////////
module macstate2(
	 input clock,
    input reset,
    output reg [4:0] salida,
    input AWvalid,
    input Wvalid,Bready,
    input ARvalid,Rready,
    input vel
    );
	
	reg [3:0] state,nexstate;
	parameter reposo = 4'd0000;
   parameter lectura = 4'b0001;
   parameter waitR = 4'b0010;
   parameter escritura = 4'b0011;
   parameter waitW = 4'b0100;
   parameter delay1 = 4'b0101;
	parameter delay2=4'b0110;
	parameter delay3=4'b0111;
	parameter delay4=4'b1000;
	parameter delay5=4'b1001;
	parameter delay6=4'b1010;
	parameter delay7=4'b1011;
	//asignacion estado siguiente
	
	always @(state,ARvalid,AWvalid,Wvalid,Bready,Rready,vel) begin
		case (state)
            reposo : begin
               if (ARvalid) begin
                  nexstate = lectura;
					end
               else if (AWvalid) begin
                  nexstate = waitW;
					end
               else begin
                  nexstate = reposo;
					end
            end
				
            lectura : begin
            	if(!vel) begin
                   nexstate = delay4;
                end
                else begin
                	nexstate=delay7;
                end
                
            end
				
            delay4 : begin
               nexstate=delay5;
            end
				
            delay5 : begin
               nexstate=delay6;
            end
				
				delay6: begin
					nexstate=delay7;
				end
				
				delay7: begin
					if (Rready) begin
						nexstate=reposo;
					end
					else begin
						nexstate=delay7;
					end
				end
				
				waitW : begin
               if (Wvalid) begin
                  nexstate = escritura;
					end
               else begin
                  nexstate = waitW;
					end
            end
				
			escritura : begin
              if (!vel) begin
              	nexstate=delay1;
              end
              else begin
              	nexstate=delay3;
              end
            end
				
				
            delay1 : begin
					nexstate=delay2;
            end
				
				delay2: begin
					nexstate=delay3;
				end
				
				delay3: begin
					if (Bready) begin
						nexstate=reposo;
					end
					else begin
						nexstate=delay3;
					end
				end
					
            default : begin  // Fault Recovery
               nexstate = reposo;
            end   
         endcase
		end
		
		// asignacion sincrona
		always @(posedge clock)
			if(reset == 0) state <= 3'b0;
			else state <= nexstate;
		
		// asignacion salidas
		
		always @(state) begin
			if (state==4'b0)
				salida=5'b00000;
			else if(state==4'b1)
				salida=5'b10000;
			else if (state==4'b010)
				salida=5'b11000;
			else if (state==4'b011)
				salida=5'b00110;
			else if (state==4'b100)
				salida=5'b00100;
			else if (state==4'b101)
				salida=5'b00110;
			else if (state==4'b110)
				salida=5'b00110;
			else if (state==4'b111)
				salida=5'b00111;
			else if (state==4'b1000)
				salida=5'b10000;
			else if (state==4'b1001)
				salida=5'b10000;
			else if (state==4'b1010)
				salida=5'b10000;
			else if (state==4'b1011)
				salida=5'b11000;
			else
				salida=5'b0;
			
			
		end
				
				
		
		

endmodule

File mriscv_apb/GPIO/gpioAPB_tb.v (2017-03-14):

`timescale 1ns / 1ps


module gpioAPB_tb;

	// Inputs
	reg clock;
	reg reset;
	reg [31:0] Paddr;
	reg Penable;
	reg Pwrite;
	reg [31:0] Pwdata;
	reg [7:0]pindata;
	reg Psel;
	reg [3:0] strobe;

	// Outputs
	wire [31:0] Prdata;
	wire [7:0] Rx;
	wire [7:0] datanw;
	wire [7:0] Tx;
	wire [7:0] DSE;
	wire Pready;

	// Instantiate the Unit Under Test (UUT)
	gpioAPB uut (
		.clock(clock), 
		.reset(reset), 
		.Paddr(Paddr), 
		.Penable(Penable), 
		.Pwrite(Pwrite), 
		.Pwdata(Pwdata), 
		.pindata(pindata),  
		.Psel(Psel), 
		.Prdata(Prdata), 
		.Rx(Rx), 
		.datanw(datanw), 
		.Tx(Tx), 
		.DSE(DSE), 
		.Pready(Pready), 
		.strobe(strobe)
	);
	always #1 clock=~clock;
	initial begin
		// Initialize Inputs
		clock = 0;
		reset = 0;
		Paddr = 0;
		Penable = 0;
		Pwrite = 0;
		Pwdata = 0;
		pindata =8'd0;
		Psel = 0;
		strobe = 0;
		
		
		// lectura
		#5;
		reset = 1;
		Paddr = 32'habcfdef;
		Penable = 1;
		Pwrite = 0;
		Pwdata = 32'h4567abcf;;
		pindata = 8'b10110101;
		Psel = 1;
		
		#5;
		reset=0;
		Penable=0;
		Paddr = 32'h348cf01f;
		
		
		// escritura
		#5;
		reset=1;
		Penable=1;
		Pwrite=1;
		pindata = 8'hff;
		
		#5;
		reset=0;
		Pwrite=0;
		Penable=0;
		Paddr = 32'h34;
		
		// lectura
		#5;
		reset=1;
		Penable=1;
		
		
		#5;
		reset=0;
		Penable=0;
		
		
		// escritura
		#5;
		reset=1;
		Penable=1;
		Pwrite=1;
		pindata = 8'h2a;
		Paddr = 32'h3a;
		
		#5;
		reset=0;
		Pwrite=0;
		Penable=0;
		#1;
		$finish;

		// Add stimulus here

	end
      
endmodule

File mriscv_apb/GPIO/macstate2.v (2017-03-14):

`timescale 1ns / 1ps

//////////////////////////////////////////////////////////////////////////////////
module macstate2(
	 input clock,
    input reset,
    output reg Pready,
    input Penable,
    input Pwrite,
	 input vel
    );
	
	reg [3:0] state,nexstate;
	parameter reposo = 4'd0;
   parameter sel = 4'b0001;
   parameter lectura = 4'b010;
   parameter waitR = 4'b0011;
   parameter endR = 4'b0100;
   parameter escritura = 4'b0101;
	parameter waitW = 4'b0110;
	parameter endW = 4'b0111;
	parameter delay1=4'b1000;
	parameter delay2=4'b1001;
	parameter delay3=4'b1010;
	parameter delay4=4'b1011;
	parameter delay5=4'b1100;
	parameter delay6=4'b1101;
	//asignacion estado siguiente
	
	always @(Pwrite,Penable,state) begin
		case (state)
            reposo : begin
               if (Penable) begin
                  nexstate = sel;
					end
               else begin
						nexstate = reposo;
					end
               
            end
            sel : begin
               if (!Pwrite) begin
                  nexstate = lectura;
					end
               else begin
                  nexstate = escritura;
					end
            end
            lectura : begin
					if(!vel) begin
                  nexstate = delay1;
					end
					else begin
						nexstate=endR;
					end
				end
               
				
				delay1 : begin
               nexstate=delay2;
            end
				
				delay2 : begin
               nexstate=delay3;
            end
				
				delay3 : begin
               nexstate=waitR;
            end
				
            waitR : begin
                  nexstate =endR;
            end
				
				endR : begin
					nexstate=reposo;
				end

            escritura : begin
					if (!vel) begin
                  nexstate = delay4;
					end
					else begin
						nexstate=endW;
					end
            end
				
				delay4 : begin
               nexstate=delay5;
            end
				
				delay5 : begin
               nexstate=delay6;
            end
				
				delay6 : begin
               nexstate=waitW;
            end
				
				waitW : begin
					nexstate=endW;
				end
				
				endW : begin
					nexstate=reposo;
				end
				
            default : begin  // Fault Recovery
               nexstate = reposo;
            end   
         endcase
		end
		
		// asignacion sincrona
		always @(posedge clock)
			if(reset == 0) state <= 4'b0;
			else state <= nexstate;
		
		// asignacion salidas
		
		always @(state) begin
			if (state==4'b0)
				Pready=0;
			else if(state==4'b1)
				Pready=0;
			else if (state==4'b0010)
				Pready=0;
			else if (state==4'b0011)
				Pready=1;
			else if (state==4'b0100)
				Pready=1;
			else if(state==4'b0101)
				Pready=0;
			else if(state==4'b0110)
				Pready=1;
			else if(state==4'b0111)
				Pready=1;
			else if(state==4'b1000)
				Pready=0;
			else if(state==4'b1001)
				Pready=0;
			else if(state==4'b1010)
				Pready=0;
			else if(state==4'b1011)
				Pready=0;
			else if(state==4'b1100)
				Pready=0;
				
			else
				Pready=0;
		end

endmodule

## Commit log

2016-10-02 Add board things
    [Testing_board_CIDIC_rev_aamaya.brd, Testing_board_CIDIC_rev_aamaya.csv, Testing_board_CIDIC_rev_aamaya.sch]
2016-11-28 Create .gitignore
    Currently just EagleCAD files.
2016-12-27 Add files via upload
    A Fully-Synthesized TRNG with Lightweight Cellular-Automata Based Post-Processing Stage in 130nm CMOS
2017-03-13 Moved submodule mriscvcore to PowerAnalysis
2017-04-12 Workaround for verilog sim in mriscv_vivado
    [impl_axi_tb.v]
2017-04-12 Workaround for firmware utilization
    [impl_axi_tb.v]
2018-02-28 Add priority encoder missing

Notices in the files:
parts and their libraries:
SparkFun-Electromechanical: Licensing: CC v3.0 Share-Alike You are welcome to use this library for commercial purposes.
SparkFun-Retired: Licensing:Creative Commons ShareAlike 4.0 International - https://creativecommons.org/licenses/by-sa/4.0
